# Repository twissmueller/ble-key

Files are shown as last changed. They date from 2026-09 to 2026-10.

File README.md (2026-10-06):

# ble-key

A Bluetooth Low Energy interface for a Morse **key**, built on a Seeed Studio XIAO board —
either the [XIAO ESP32-S3](https://wiki.seeedstudio.com/xiao_esp32s3_getting_started/) or the
[XIAO nRF52840](https://wiki.seeedstudio.com/XIAO_BLE/).

Plug in your own straight key or iambic paddle. The board reads the contacts (dit / dah),
debounces them, and streams **timed keying edges** over BLE as notifications to the
[Longpath](https://wissmueller.net/en/longpath.html) Morse-training app, which produces the
audio/sidetone and does the training. The device itself makes no sound — it's purely the
key interface. The onboard LED gives instant, BLE-independent visual feedback while keying.

The BLE contract below is simple and app-agnostic — anything that speaks GATT can consume it.
Both boards implement it identically; the app cannot tell them apart.

## Repository layout

| Path | What |
|---|---|
| [`esp32s3/`](esp32s3/) | XIAO ESP32-S3: firmware, pins and wiring, the battery mod ([BATTERY.md](esp32s3/BATTERY.md)) |
| [`nrf52840/`](nrf52840/) | XIAO nRF52840: firmware, pins and wiring, battery |
| [`lib/BleKeyCore/`](lib/BleKeyCore/src/BleKeyCore.h) | Shared firmware: the BLE contract, debounce, LiPo curve, power states |
| [`enclosure/`](enclosure/) | Printable cases — the XIAO case fits both boards |
| `flash.sh`, `monitor.sh` | Build, flash and watch either board |

## Which board?

| | XIAO ESP32-S3 | XIAO nRF52840 |
|---|---|---|
| Keying, LED, BLE contract | ✓ | ✓ |
| Wiring of the paddle jack | `D1` tip, `D2` ring, `GND` sleeve | the same |
| Battery level | LiPo **plus two dividers** soldered on | LiPo only — divider is on the board |
| Charging / charged | extra charge-sense wire | read from the charger on the board |
| Idle sleep | deep sleep, ~14 µA | System OFF, a few µA |
| Current while connected | tens of mA | a few mA (typical figures, not measured here) |

For a battery key the nRF52840 is the better choice: no extra parts and much longer runtime.
The ESP32-S3 key stays supported.

## Getting a key

The BLE key is open hardware — get one in whichever way suits you:

1. **Build it yourself** — source the parts ([Hardware](#hardware)) and flash the firmware
   ([Build & flash](#build--flash)); everything you need is in this repository.
2. **Order a parts kit** — I'll send you the board and connectors, you assemble and flash.
3. **Order a ready-built key** — assembled, flashed, and tested.

For a parts kit or a ready-built key, email
[hello@wissmueller.net](mailto:hello@wissmueller.net) with your shipping address. The Longpath
app offers the same three options (with pre-filled order emails) in its BLE-key dialog — keep
that dialog and this section in sync.

## BLE contract

The device advertises as **`Paddle`** with one service and one notify characteristic.
On every debounced paddle edge it sends a **5-byte little-endian** packet:

```
byte 0     : event   (uint8)
bytes 1..4 : millis  (uint32, little-endian) — device millis() at the edge
```

Events:

| Value | Event |
|---|---|
| `0` | `DIT_DOWN` |
| `1` | `DIT_UP` |
| `2` | `DAH_DOWN` |
| `3` | `DAH_UP` |

The client reconstructs element and gap timing from consecutive timestamps. The board
re-advertises automatically after a central disconnects, so a client can reconnect
without power-cycling.

### Battery level

With a battery the key additionally exposes the SIG-standard
**Battery Service `0x180F`** with the **Battery Level characteristic `0x2A19`** (`uint8`,
0–100 %, read + notify). The level is re-measured every 10 s while the key is idle and
notified only when it changes; a client reads it once after connecting and then subscribes.
The service is *not* advertised — clients find it during service discovery — and it sits
next to the Longpath service without touching the packet format or UUIDs above. Clients
that do not know it, and older app builds, simply ignore it. Whether a key without a cell
exposes the service at all depends on the board (see its README); either way the Longpath
app then shows no level.

The percentage comes from an open-circuit LiPo discharge curve (3.30 V → 0 %, 4.20 V →
100 %, flat in the middle), not a linear map. On USB power the
measurement would only see the charger, so the key publishes **`0xFF` = level unknown** instead
of a percentage — outside the SIG's 0–100 on purpose; Longpath shows no level for it, other
clients should treat it the same way — and the idle sleep is off. Below 3.5 V the onboard
LED double-blinks once at boot, independently of BLE.

### Battery power state

Next to the level the same service carries the SIG-standard **Battery Power State
characteristic `0x2A1A`** (`uint8`, read + notify): bits 0–1 *present*, bits 2–3
*discharging*, bits 4–5 *charging* (each 2 = no, 3 = yes; 0 = unknown), bits 6–7 unused.
The key publishes five values:

| Meaning | Value  | present | discharging | charging |
|---|---|---|---|---|
| unknown | `0x00` | ? | ? | ? |
| on cell | `0x2F` | yes | yes | no |
| charging  | `0x3B` | yes | no | yes |
| charged | `0x2B` | yes | no | no |
| no cell | `0x02` | no | — | — |

Off USB a plausible cell reading means *on cell*. On USB the charger's status line is the
only evidence; how each board reads it is in its README. Anything the key cannot vouch for
stays *unknown*. While *charging* or *charged* the level in `0x2A19`
is the live reading of the cell under charge instead of `0xFF` — a few points high and
climbing; the Longpath app shows it next to "charging" and forces 100 % once the key reports
*charged*. In every other state on USB the level stays `0xFF`. Notified only on change; a
client reads it once after connecting and subscribes.

### Idle sleep

A battery key enters deep sleep after ten minutes without a paddle edge.
It disconnects the central first, so a client sees a clean disconnect rather than a
supervision timeout, and wakes on either paddle line going LOW. Waking is a reset: the key
advertises again after about half a second, and `millis()` restarts at 0 — clients must
treat a reconnect as a timing resync (Longpath does). A key on USB never sleeps.

### UUIDs

The service and characteristic UUIDs in [`BleKeyCore.h`](lib/BleKeyCore/src/BleKeyCore.h) are the **fixed Longpath contract**
— the app looks for exactly this service, so leave them unchanged if your key should work
with Longpath (whether self-built, from a kit, or bought ready-made). Only when building
for a *different* client should you mint your own pair (`uuidgen`, run twice) and replace
`SVC_UUID` / `CHR_UUID` there — both boards pick them up.

## Build & flash

Requires [`arduino-cli`](https://arduino.github.io/arduino-cli/) and the core for your board:

```sh
# XIAO ESP32-S3
arduino-cli core install esp32:esp32
arduino-cli lib install "NimBLE-Arduino"

# XIAO nRF52840 (Seeed's non-mbed core, which brings the Bluefruit BLE library)
arduino-cli config add board_manager.additional_urls \
  https://files.seeedstudio.com/arduino/package_seeeduino_boards_index.json
arduino-cli core update-index
arduino-cli core install Seeeduino:nrf52
```

Then:

```sh
./flash.sh esp32s3            # or: ./flash.sh nrf52840
./flash.sh nrf52840 /dev/cu.usbmodemXXXX   # pass the port explicitly

./monitor.sh                  # serial monitor at 115200 baud, either board
```

`flash.sh` passes the shared `lib/BleKeyCore` to arduino-cli with `--library`; a manual
`arduino-cli compile` needs the same flag. Bench builds and board-specific notes are in
[esp32s3/README.md](esp32s3/README.md) and [nrf52840/README.md](nrf52840/README.md).

## License

[MIT](LICENSE) © 2026 Tobias Wissmüller

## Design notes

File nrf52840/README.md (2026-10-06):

# ble-key on the XIAO nRF52840

Firmware for the [Seeed Studio XIAO nRF52840](https://wiki.seeedstudio.com/XIAO_BLE/). The BLE
contract, the build tools and the case are shared with the ESP32-S3 key and described in the
[main README](../README.md). The board-independent firmware lives in
[`../lib/BleKeyCore`](../lib/BleKeyCore/src/BleKeyCore.h); this sketch adds the Bluefruit BLE
stack, the pins, the battery readings and System OFF.

## Pins and wiring

| Signal | XIAO pin | nRF pin | Notes |
|---|---|---|---|
| Dit | `D2` | P0.28 | `INPUT_PULLUP`, pressed = LOW |
| Dah | `D1` | P0.03 | `INPUT_PULLUP`, pressed = LOW |
| Keying LED  | blue LED | P0.06 | active-low |
| Low battery | red LED  | P0.26 | active-low, double blink at boot below 3.5 V |
| Battery | on board | P0.31 | 1 MΩ / 510 kΩ divider, enabled by P0.14 LOW |
| Charging | on board | P0.17 | BQ25100 `~CHG`, LOW while charging |
| USB power | on chip  | — | the nRF52840's VBUS detector |

The paddle jack is wired exactly as on the ESP32-S3 (`D1` tip, `D2` ring, `GND` sleeve). With
that wiring, dit and dah came out swapped on the nRF prototype, so the firmware reads dit on
`D2` and dah on `D1` — the ESP32-S3 sketch does it the other way round. For
the battery only the cell is soldered on — none of the resistors or wires of the ESP32-S3's
battery strips are needed here:

Wiring: XIAO nRF52840 to a 3.5 mm TRS jack — D1 to tip (dit), D2 to ring (dah), GND to sleeve; optional LiPo on the BAT pads, with the battery divider on P0.31, the BQ25100's ~CHG on P0.17 and the VBUS detector already on the board

## Battery

Solder a single-cell LiPo with protection circuit to the `BAT` pads on the underside — that is
the whole mod. The XIAO nRF52840 has the charger, the voltage divider and the charge-status
line on board, and the chip sees USB power itself. Cell choice, polarity and soldering are the
same as for the ESP32-S3 key: see [`../esp32s3/BATTERY.md`](../esp32s3/BATTERY.md) up to and
excluding "The voltage divider".

- **Battery Service:** always present. Off USB the key can only be running from a cell; on USB
  without one it reports the level as `0xFF` (unknown), like the ESP32-S3 key.
- **Power state:** off USB a plausible reading means *on cell*. On USB, `~CHG` held low for two
  3 s windows means *charging*; released after that, *charged*. Released from the start (a full
  cell or no cell) stays *unknown*. *No cell* is never reported — what the BQ25100 does on
  `~CHG` without a cell is not verified yet.
- **Charge current:** the core's default, 50 mA. Seeed's wiki describes how P0.13 switches it to
  100 mA; the firmware leaves it alone.
- **VBAT_ENABLE (P0.14)** is driven LOW for good: with it HIGH, as the core leaves it, a full
  cell lifts P0.31 above the chip's supply through the divider. LOW costs about 3 µA.

## Idle sleep

Off USB the key enters **System OFF** after ten idle minutes, with both paddle lines armed
(pull-up, sense LOW). The next dit or dah wakes it; that press is consumed by the boot, as on
the ESP32-S3. Plugging in USB wakes a sleeping key too. The GPIO latch tells the firmware which
paddle woke it (`[paddle] woke on key press (dah)`).

## Build & flash

```sh
./flash.sh nrf52840           # from the repository root
```

FQBN `Seeeduino:nrf52:xiaonRF52840` — Seeed's **non-mbed** core, which brings Adafruit's
Bluefruit library. `flash.sh` uploads over the USB serial bootloader. Two quirks of that core
it works around: it calls `python` (macOS only has `python3`), and its `adafruit-nrfutil` stops
under an ASCII locale.

If the board does not show up as a serial port (crashed firmware), double-tap the reset button:
the bootloader comes up with its own port and a USB drive, and `flash.sh` works
again.

### Bench build

Shorter idle sleep, from the repository root:

```sh
arduino-cli compile --fqbn Seeeduino:nrf52:xiaonRF52840 --library lib/BleKeyCore \
  --build-property "compiler.cpp.extra_flags=-DIDLE_SLEEP_MS=20000" nrf52840
```

System OFF has no timer, so there is no `SLEEP_TEST_TIMER_S` here; wake the key with the paddle.
The serial monitor misses the boot log after a wake; the firmware repeats the essentials 3 s
after boot (`[paddle] ready — woke on dit, advertising`).

## Measured

- **No cell, on USB (6 October 2026):** the battery pin reads 3748 mV — the charger's output,
  not a cell. The key correctly publishes the level as `0xFF` and the power state as unknown.
  This is why a reading on USB is never trusted without `~CHG` having shown a charge.

## Not yet measured

- Sleep current in System OFF and current while connected.
- Battery readings against a meter (divider tolerance, ADC offset).
- `~CHG` at the end of a charge (with no cell it did not report charging).
- Which of the case's light holes the RGB LED lines up with.

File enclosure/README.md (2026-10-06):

# Printable cases

`enclosure.py` (build123d, Python CAD) builds the case for a XIAO ESP32-S3 or XIAO nRF52840 with a
3.5 mm paddle jack, in two versions. It writes STEP and STL per part to `out/`, plus a lid STL turned
over for printing. `preview.html` shows both cases in 3D after the script has run.

| Case | Outer size, Cliff FC681374V (default) | with `--jack pj392` |
|---|---|---|
| USB only | 48.5 × 25.0 × 14.1 mm | 43.0 × 25.0 × 13.6 mm |
| Battery under the board | 53.2 × 25.3 × 20.2 mm | 53.2 × 25.3 × 19.2 mm |

**The jack.** The default is the **Cliff FC681374V** (Reichelt 228160): M8 × 0.75 thread through an
8.5 mm hole in the full 2 mm wall, ring nut outside, square body 10.5 × 9 × 13.5 mm plus 4 mm pins
inside. A block under the lid sits on the body's flat top, so tightening the nut cannot turn it.
Pins: 3 = tip (D1), 2 = ring (D2), 1 = sleeve (GND), 4 = switch contact, unused. The **PJ-392**
(TinyTronics; round 8 mm body, 6.5 mm hole, 12 mm deep) still works with `--jack pj392`, which
writes the same file names, so regenerate before printing.

```bash
uv venv --python 3.12 .venv && uv pip install --python .venv/bin/python -r requirements.txt
.venv/bin/python enclosure.py          # MJF / SLA print service, 0.25 mm fit
.venv/bin/python enclosure.py --fdm    # own FDM printer (PETG), 0.35 mm fit → out/usb-fdm/, out/battery-fdm/
.venv/bin/python enclosure.py --snap-test   # FDM test pieces for the snap lips → out/snap-test-fdm/
.venv/bin/python enclosure.py --jack pj392   # any of the above for the PJ-392 instead of the Cliff jack
```

**Printing the XIAO case in PETG on an FDM printer** (e.g. Bambu Lab A1 mini): use
`out/usb-fdm/ble-key-usb-fdm-base.stl` upright, floor on the plate, and
`out/usb-fdm/ble-key-usb-fdm-lid-print.stl` (already turned over). 0.2 mm layers, 3 walls, 20 %
infill, no supports. Screws: 2 × countersunk self-tapping 2.2 × 6.5 (DIN 7982); the lid has 90°
countersinks for them.

**Holding the board:** in both XIAO cases the board clicks in: four springy snap lips beside its
corners hook 0.25 mm over the long edges, so it stays put with the lid off. With the lid on, the
tab presses on the USB-C socket and two stiff L-shaped ribs press on the far corners. If a lip
holds too little or breaks, tune `SNAP_HOOK`, `SNAP_T` and `SNAP_ROOT` in `enclosure.py`. Try the
fit first with the test pieces from `--snap-test`: a 5.8 mm slice of each base around the far
supports, and a 15 mm stand-in for the board's end (or use the real XIAO).

## The XIAO battery case

Three layers instead of a second compartment: the LP-552035 lies flat on the floor, a 3 mm wiring
layer sits above it, and the XIAO rests on four 45° brackets on the side walls on top (no
supports needed when printing). Each bracket has a springy snap lip with a 0.25 mm hook over the
board's edge, so the board clicks in and stays put with the lid off; with the lid on, two stiff
ribs hung from its lip press the far corners down right above the brackets. The BAT pads and the
paddle wires are soldered on the board's underside, so every wire runs in that layer, out of sight. The jack sits above the cell; under it
is a 10 mm bay for the mated JST-PH pair and the spare lead, separated from the cell by a low rib
with a gap for the lead. Four countersunk screws go into bosses that hang from the side walls
above the cell. Keep the joints under the board flat — 3 mm is the limit — and tape the cell to
the floor, it has 0.5 mm of play upwards.

## XIAO ESP32-S3 and XIAO nRF52840

Both XIAO cases fit either board: the two share the outline, board thickness and USB-C position
(checked against Seeed's STEP models, `vendor/XIAO-ESP32S3 v2.step` and
`vendor/nrf/XIAO-nRF52840 v15.step`), and the lid's two hold-down ribs sit on bare board on both.
The light holes are placed for the ESP32-S3's LEDs; on the nRF52840 they are not verified.

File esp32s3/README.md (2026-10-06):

# ble-key on the XIAO ESP32-S3

Firmware and wiring for the [Seeed Studio XIAO ESP32-S3](https://wiki.seeedstudio.com/xiao_esp32s3_getting_started/).
The BLE contract, the build tools and the case are shared with the nRF52840 key and described in
the [main README](../README.md). The board-independent firmware lives in
[`../lib/BleKeyCore`](../lib/BleKeyCore/src/BleKeyCore.h); this sketch adds NimBLE, the pins,
the ADC and the deep sleep.

## Pins and wiring

| Signal | XIAO pin | GPIO | Notes |
|---|---|---|---|
| Dit | `D1` | GPIO2  | Tip, `INPUT_PULLUP`, pressed = LOW |
| Dah | `D2` | GPIO3  | Ring, `INPUT_PULLUP`, pressed = LOW |
| LED | `GPIO21` | — | `LED_BUILTIN`, active-low |
| Battery | `A0` | GPIO1  | Divider tap, ADC — battery mod only |
| USB power | `D10` | GPIO9  | Divider tap from `5V` (VBUS), ADC — battery mod only |
| Charge LED  | `D3` | GPIO4  | Tap on the charge-LED net, `INPUT_PULLUP`, LOW = LED on — charge-sense wire only |

Wire each key/paddle contact between its input pin and ground; the internal pull-ups mean
no external resistors are needed. A straight key uses the dit line only; an iambic paddle
uses both. The tip/ring assignment matches a standard 3.5 mm TRS paddle plug:

Wiring: XIAO ESP32-S3 to a 3.5 mm TRS jack — D1 to tip (dit), D2 to ring (dah), GND to sleeve; optional LiPo on the BAT pads with a 2 × 220 kΩ divider into A0, a second 2 × 220 kΩ divider from 5V into D10 to sense USB power, and the optional charge-sense wire from the charge LED's cathode pad throu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

## Battery (optional)

The key runs from USB-C as it is. For a cordless key, solder a single-cell LiPo to the
`BAT` pads on the underside of the XIAO — it has the charger on board — and add a
**2 × 220 kΩ voltage divider** from `BAT+` to `GND`, tapped into `A0`, so the firmware can
measure the cell and report its level to the app. Add a **second 2 × 220 kΩ divider from the
`5V` pin to `GND`, tapped into `D10`**: the 5V pin is USB VBUS, so this tells the firmware
when the key is on USB power — from a host, a charger or a power bank alike. That matters
because on USB the `BAT+` pad carries the charger's output, not the cell, and would read as a
meaningless "62 %" even with no cell fitted. Cell choice, polarity, soldering order and
runtime expectations are in [BATTERY.md](BATTERY.md).

To see *charging* in the app as well, add the **charge-sense wire**: one wire (through a
100 kΩ series resistor) from the net of the red charge LED into `D3`. The charge IC drives
that LED and nothing else — flashing while a cell charges, off when it is full, solid for
~30 s after plug-in without a cell — and reading it is the only way the firmware can tell
those apart. With the wire the key reports charging / charged / no cell over BLE and keeps
publishing the live level while charging; without it, USB shows the plain connected chip
as before. Details in [BATTERY.md](BATTERY.md#the-charge-sense-wire); the last strip of the wiring diagram shows it.

One build fits every key: at boot the firmware checks whether the mod is actually fitted
(VBUS on `D10`, or a plausible cell voltage on `A0`, steady over a few samples) and switches
the battery features on or off accordingly. A battery key reports its level over BLE and
**deep-sleeps after ten idle minutes** — the next dit or dah wakes it (that press is consumed
by the boot; keying resumes with the following one, and the Longpath app reconnects on its
own). A stock USB key exposes no Battery Service and never sleeps. To leave the battery code
out of the image altogether, build with `-DBATTERY_MOD=0` (see [Bench builds](#bench-builds)).

## How the power state is read

Off USB a plausible cell reading means *on cell*. On USB the charge LED, read through the
charge-sense wire on `D3`, is the only evidence: flashing → *charging*; dark for two windows
after having flashed → *charged*; solid for two windows without ever flashing → *no cell*.
Dark from the start says nothing (a key booted on USB, a cell that was already full, or a key
without the wire) and stays *unknown*. USB power itself is sensed on `D10`.

## Idle sleep

The battery key deep-sleeps after ten idle minutes and wakes on either paddle line through
ext1. Details, including the RTC pull-up handling that makes this work, are in
[BATTERY.md](BATTERY.md#idle-sleep).

## Build & flash

```sh
../flash.sh esp32s3           # from the repository root: ./flash.sh esp32s3
```

FQBN `esp32:esp32:XIAO_ESP32S3`, BLE through [NimBLE-Arduino](https://github.com/h2zero/NimBLE-Arduino).

### Bench builds

Two compile-time overrides make the idle sleep testable without waiting ten minutes
(run from the repository root):

```sh
# sleep after 20 s instead of 10 min
arduino-cli compile --fqbn esp32:esp32:XIAO_ESP32S3 --library lib/BleKeyCore \
  --build-property "compiler.cpp.extra_flags=-DIDLE_SLEEP_MS=20000" esp32s3
# additionally wake by timer after 15 s, to test the wake/boot path without a key
arduino-cli compile --fqbn esp32:esp32:XIAO_ESP32S3 --library lib/BleKeyCore \
  --build-property "compiler.cpp.extra_flags=-DIDLE_SLEEP_MS=20000 -DSLEEP_TEST_TIMER_S=15" esp32s3

# leave the battery code out of the image entirely (no ADC, no Battery Service, no sleep)
arduino-cli compile --fqbn esp32:esp32:XIAO_ESP32S3 --library lib/BleKeyCore \
  --build-property "compiler.cpp.extra_flags=-DBATTERY_MOD=0" esp32s3
```

A sleeping key has no USB port (native USB dies with the chip), so a build that cannot wake
can only be re-flashed after a power cycle. Hold the key down while plugging USB back in —
a held paddle keeps the firmware awake indefinitely — and flash then. The serial monitor
misses everything printed before it attaches, which after a wake is the whole boot log;
the firmware therefore repeats the essentials once, 3 s after boot
(`[paddle] ready — woke on dit, advertising`).

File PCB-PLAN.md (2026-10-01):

# Custom PCB plan — nRF52840 key, built by AISLER

**Status:** schematic, layout and case done (`hardware/`, `enclosure/`); design uploaded to AISLER
and quoted on 1 October 2026; nothing ordered. Prices are **net (no VAT)** unless marked. Figures
marked *estimate* do not come from a price list or quote.

## Why

The XIAO ESP32-S3 does far more than the key needs (two cores, Wi-Fi, camera support) and costs
battery life. The key needs BLE, two inputs, a battery measurement, a charger and USB-C. A custom
board with an **nRF52840** module gives:

- much lower power draw while connected, so the battery version lasts far longer between charges;
- no hand wiring: USB-C, the 3.5 mm jack and the battery connector sit on the board, and the
  housing has openings exactly where they are;
- real charge and USB-power signals from the charger chip instead of the two voltage dividers and
  the soldered charge-sense wire;
- the same product every time, assembled by AISLER in Germany.

It is **not cheaper per unit** than the XIAO build at 30 pieces. The gain is battery life, build
quality and no assembly work.

## The board

**48 × 27 mm, 2 layers, 1.6 mm, ENIG**, all parts on the top side, all SMD (see `hardware/`).

| Function | Part | Price @30 | Source |
|---|---|---|---|
| BLE + MCU | Raytac **MDBT50Q-1MV2** (nRF52840, chip antenna, FCC/CE/TELEC certified), sold as Seeed 113990582 | 10.27 € | [DigiKey](https://www.digikey.de/de/products/detail/seeed-technology-co-ltd/113990582/9697025) |
| Charger with power path | TI **BQ24074RGTR** — runs the key from USB while it charges; CHG and PGOOD pins go straight to GPIOs | 1.41 € | [DigiKey](https://www.digikey.de/de/products/detail/texas-instruments/BQ24074RGTR/2047269) |
| USB-C | GCT **USB4105-GF-A** (USB 2.0, 16 pin) | 0.54 € | [DigiKey](https://www.digikey.de/de/products/detail/gct/USB4105-GF-A/11198441) |
| Paddle jack | Same Sky **SJ-3523-SMT-TR** (3.5 mm TRS, right angle) | 0.60 € | [DigiKey](https://www.digikey.de/de/products/detail/same-sky-formerly-cui-devices/SJ-3523-SMT-TR/281297) |
| Battery connector | JST **S2B-PH-SM4-TB** (PH 2.0, SMD) | 0.36 € | [DigiKey](https://www.digikey.de/de/products/detail/jst-sales-america-inc/S2B-PH-SM4-TB/926655) |
| USB ESD protection | ST **USBLC6-2SC6** | 0.28 € | [DigiKey](https://www.digikey.de/de/products/detail/stmicroelectronics/USBLC6-2SC6/1040559) |
| Reset / bootloader button | Panasonic **EVP-AKE31A** (side push) | 0.41 € | [DigiKey](https://www.digikey.de/de/products/detail/panasonic-industry/EVP-AKE31A/8568272) |
| 2 status LEDs | Würth 150060VS75000 (0603) | 0.26 € | [DigiKey](https://www.digikey.de/de/products/detail/w%C3%BCrth-elektronik/150060VS75000/4489906) |
| Resistors, capacitors, battery divider | 0603 passives, ~15 pieces | ~1.50 € *estimate* | — |
| **Parts per board** | | **≈ 15.60 €** | |

Design notes:

- **Why this module:** it is the module on Adafruit's Feather nRF52840, so its UF2 bootloader runs
  unchanged and updates work by dragging a file onto a USB drive. Its VDDH input takes the battery
  voltage directly, so no voltage regulator is needed. The certification covers the radio, as long
  as the antenna area stays clear of copper — the module goes at a board edge.
- **The module has pads underneath (LGA).** That is fine for AISLER's machines but rules out hand
  soldering. Their guide for modules: [setting up SoMs for assembly](https://community.aisler.net/t/setting-up-socs-for-assembly/3443).
  Suitability of this exact module should be confirmed with them before the first order.
- **Battery version and USB-only version are the same board**; the USB-only key simply has no
  cell plugged in.
- **Pins follow the Feather nRF52840 where possible** (LEDs, button), so the Feather board
  definition in the Arduino core can be used without a custom one.
- **Programming pads (SWD)** for the one-time bootloader flash: SWDIO, SWCLK, GND, VDD, RESET,
  as a Tag-Connect footprint so a cable clips on without a connector on the board.
- **Charge current** set to ~175 mA (0.5 C for 350 mAh), so a full charge takes about 2½ hours
  instead of the XIAO's 7.

## Firmware

Port `ble-key.ino` to the **Adafruit nRF52 Arduino core** (Bluefruit library):

- the Longpath contract stays: same service and characteristic UUIDs, same event format, same
  Battery Service;
- battery level from the divider, USB power from PGOOD, charging from CHG — the three readings
  the current firmware has to infer from analog voltages become plain pin reads;
- deep sleep becomes nRF52 **System OFF** with wake-up on the dit or dah pin (a few µA);
- `flash.sh` switches to the Feather nRF52840 board and uploads over USB.

The port can start **now, before any board exists**, on a Seeed XIAO nRF52840 — same nRF52840
chip, same USB bootloader, and it fits the housing in `enclosure/` unchanged.

## Housing

`enclosure/board_case.py` builds the case around the board, USB-only (52.4 × 31.6 × 12.4 mm) or with
the cell in the lid above the board (52.4 × 31.6 × 18.8 mm). Printed by an outside service in MJF
PA12 (dyed black) — AISLER makes no enclosures. See `enclosure/README.md`.

## Costs

### AISLER quote, 1 October 2026

From the uploaded design (project TBHYNBKB, revision 1), with every part assigned and prices
calculated. Net prices, **plus 19 % VAT**, valid 24 hours; dispatch about 18 working days after
ordering. Service "Amazing Assembly": 2 layers, 1.6 mm, ENIG, green, one-sided assembly, 36 parts
(24 different).

| Assembled boards | Net total | Per board |
|---|---|---|
| 1 | 327.18 € | 327.18 € |
| 3 | 406.56 € | 135.52 € |
| 10 | 712.19 € | 71.22 € |
| **30** | **1,423.21 €** | **47.44 €** |

### Where the money goes

The quote splits into three parts. Bare boards and parts come straight from AISLER's own price
lists; assembly is what is left of the total.

| Per board | 1 board | 10 boards | 30 boards |
|---|---|---|---|
| Bare PCB (ENIG) | 16.42 € *(set of 3)* | ~2.70 € *(set of 12)* | 1.68 € |
| Parts, as AISLER buys them | 132.28 € | 33.23 € | ~31.40 € *(between their 10 and 50 prices)* |
| Assembly | ~178 € | ~35.50 € | ~14.40 € |
| **Total** | **327.18 €** | **71.22 €** | **47.44 €** |

The cost drivers, in order:

1. **Parts at about twice their list price.** The parts add up to about 16 € per board at
   distributor list prices, but AISLER charges 33.23 € at 10 boards and 29.57 € at 50. Their parts
   price includes "assembly surplus and sourcing and handling costs" and minimum order quantities.
   Even at 1,000 boards it is still 23.81 €.
2. **The radio module.** It is the only part AISLER marks as a large price impact: 8.85 € each as
   Seeed 113990582. The listing also says "the factory is currently not accepting orders", so stock
   is finite.
3. **Assembly setup.** Roughly 180 € for a single board and about 430 € for 30, so it is mostly a
   fixed cost per order. AISLER does not publish the rates, but the cost is known to grow with the
   number of *different* parts (24 today), more than with the number of boards.
4. **The bare board is negligible:** 1.68 € per board at 30.

Compared with the earlier estimate (27–30 € per key including the case), assembled boards alone
cost about 47 € at 30. The parts surplus and the assembly setup were both underestimated.

### Ways to bring it down

| Change | Effect |
|---|---|
| **Order more at once** | Parts drop from 33.23 € (10) to 29.57 € (50) and 26.55 € (100) per board, and the assembly setup spreads further. |
| **Fewer different parts** (24 → about 17) | Cuts the per-part setup work: <br>– drop the reset button (the bootloader is reachable over USB, recovery over SWD), which also removes the tongue from the case; <br>– use the module's internal pull-ups for PGOOD and CHG (R6, R7); <br>– one 10 µF value for all bulk capacitors (C1–C3 at the charger too, within the BQ24074's ranges); <br>– 1 kΩ instead of 470 Ω for the paddle series resistors; <br>– 5.1 kΩ for ILIM as well (about 300 mA input limit, enough for 175 mA charging); <br>– two LEDs of the same colour. |
| **Supply the module yourself** | Raytac's own listing is about 6 € including shipping, against 8.85 € plus AISLER's surplus. Costs a one-off 15 € fee per supplied part number, so it pays off from about 10 boards. It also protects the run against the Seeed listing running dry. |
| **Ask for a personal quote** | AISLER's account management quotes larger or repeat runs individually. |

Each change in the "fewer different parts" row needs a schematic change and a new upload to see
its real effect; AISLER prices only the design it has.

### JLCPCB quote, 1 October 2026

Same design, uploaded to JLCPCB (`hardware/jlcpcb/`), 30 boards, ENIG, economic assembly on the
top side. Prices in USD, before shipping (DHL about 23 $) and EU import VAT:

| Item | 30 boards |
|---|---|
| Bare boards | 76.15 $ — of which about 51 $ come from the 0.25 mm vias, which make JLCPCB add via plugging and a 4-wire test; with 0.3 mm vias the boards cost 26 $ |
| Parts (22 of 24 types) | 140.35 $ |
| Extended-part fees | 30.90 $ |
| Setup, stencil, assembly, nitrogen reflow | 17.44 $ |
| **Total without module and switch** | **264.84 $ (8.83 $ per board)** |

Not in that total, because JLCPCB has no stock: the **module** (MDBT50Q-1MV2, listed at 18.94 $
each, so about 570 $ for 30 if pre-ordered there) and the **reset switch**. With the module bought
through JLCPCB the order comes to roughly **850–870 $**, about 29 $ per board; with modules bought
elsewhere at 9–10 € each and sent in, considerably less. Either way about half of AISLER's
1,423 € net.

To order there: pre-order or consign the module and switch, tick "Confirm Parts Placement" (JLCPCB's
model of the jack sits about 0.7 mm off the pads; their engineers correct it), and keep in mind
that shipping from China and customs add a few days and the import VAT.

### Seeed Fusion quote, 1 October 2026

Same design (`hardware/seeed/`), 30 boards, ENIG, 0.25 mm drill, 4/4 mil, 0.1 mm mask dam. USD,
free DHL express shipping to Germany, before EU import VAT and coupons:

| Item | 30 boards |
|---|---|
| Bare boards | 162.70 $ (the tight drill/trace/mask rules double the board price) |
| Parts, 17 of 24 lines matched | 207.41 $ |
| Assembly | 332.70 $ |
| Setup and consumables | 65.00 $ |
| **Subtotal** | **767.81 $** |

Not yet priced: the module (Seeed SKU 113990582) and six resistor values, which Seeed checks by
hand within a working day once the order is in the cart. With the module at about 9–10 $ the total
comes to roughly **1,050–1,100 $, about 35–37 $ per board.** Per-board prices fall to 18.77 $ (50)
and 13.28 $ (100) for the matched part of the quote.

### Comparison, 30 assembled boards

| Supplier | Total | Per board | Status |
|---|---|---|---|
| AISLER (Germany) | 1,423.21 € net | 47.44 € | complete quote, all parts in stock |
| Seeed Fusion (China) | ~1,050–1,100 $ | ~35–37 $ | module and 6 resistors priced on manual review |
| JLCPCB (China) | ~850–870 $ | ~29 $ | module and reset switch out of stock there |

### Everything else (unchanged estimates)

| Item | Cost |
|---|---|
| Cells, LP-552035 | 4.18 € each ([Eckstein](https://eckstein-shop.de/LiPo-Battery-Lithium-Ion-Polymer-Battery-37V-350mAh-with-JST-PHR-2-Connector-LP552035-EN)) |
| Cases, MJF PA12, from an EU print service | ~3–6 € per case *estimate* |
| Screws, 2 × M2 × 8 per case | ~0.20 € |
| Once: Raspberry Pi Debug Probe, Tag-Connect TC2030 cable, XIAO nRF52840 for the firmware port | ~65 € *estimate* |

**Per key at 30, with battery: about 47.44 + 4.18 + ~4.50 + 0.20 ≈ 56 € net.**

### Not included: selling the keys

Selling assembled keys in the EU makes you the manufacturer, which brings costs that are not in
the tables above and need checking before the first sale:

- **CE marking under the Radio Equipment Directive.** The certified module helps a lot, but the
  finished product still needs a declaration of conformity; a pre-scan at a test lab is the usual
  safeguard. This can cost more than the whole production run.
- **WEEE registration** (stiftung ear) for electronic devices sold in Germany.
- **Battery registration** (BattG / EU battery regulation) if keys ship with a cell — or sell the
  cell separately, or let buyers fit their own.

Kits the buyer assembles and the open-hardware files themselves are a different situation.

## Order of work

1. **Firmware port** on a XIAO nRF52840 — proves BLE, sleep and battery life before any money
   goes into boards.
2. ~~Schematic and layout in KiCad~~ — done, with MPN fields filled in.
3. ~~Upload to AISLER~~ — done, quote above. Still to do: confirm the module's bottom pads with
   their support, and decide on the cost reductions.
4. **Prototype run of 3**, housing variant printed alongside. Test charging, range, sleep current.
5. Fixes, then **production run of 30**.

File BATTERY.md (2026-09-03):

# Battery mod — running the key on a LiPo

**Status:** hardware path is verified against the Seeed wiki and low-risk. The firmware
measures the cell through a 2 × 220 kΩ divider, reports the level to the app over the
standard BLE Battery Service (see [Battery level](#battery-level-over-ble)) and deep-sleeps
after ten idle minutes, waking on the next key press (see [Idle sleep](#idle-sleep)). What
is left is measuring on real hardware (see [TODO](#todo--firmware-work)). The stock,
USB-powered key is unaffected — this is an optional mod for people who want a cordless key.

The [XIAO ESP32-S3](https://wiki.seeedstudio.com/xiao_esp32s3_getting_started/) has a LiPo
charger on board, so going cordless needs no extra charging module: solder a cell to two
pads and the same USB-C port that flashes the board also charges it.

## What the board gives you

- Two solder pads on the **underside**, labelled `BAT`, for a single-cell 3.7 V LiPo.
- An **on-board charge IC**. Plug in USB-C and the cell charges while the board keeps
  running and keying — no need to disconnect anything.
- A red charge LED: on when USB is connected *without* a battery (it gives up after ~30 s),
  flashing while charging, off when the cell is full.
- **14 µA in deep sleep** (per Seeed's specification table), which is what makes a
  battery-powered key practical at all.

Three constraints that shape every decision below:

- **The charge current is only 50 mA** (3.8 mA trickle) on the plain XIAO ESP32-S3. Note
  that the *Sense* variant charges at 100 mA — do not carry that number over. 50 mA is
  fixed in hardware and cannot be raised in firmware, so **capacity costs you charge
  time**: a 500 mAh cell needs roughly 10 hours from empty. That is fine overnight and
  painful otherwise.
- The charger has **no NTC / temperature input**. The cell's own protection circuit is the
  only safety net, which is why the cell choice below is not optional.
- Seeed states plainly that there is **no GPIO for battery voltage**: *"we cannot get the
  battery voltage at the software level by reading the analog value of one of the GPIOs."*
  The state-of-charge display therefore needs an external divider — two resistors, see
  [The voltage divider](#the-voltage-divider).

## Choosing a cell

A single-cell 3.7 V LiPo pouch with an **integrated protection circuit (PCM)** —
over-charge, over-discharge, over-current and short-circuit protection built into the tab
end. Cells sold with a JST-PH connector normally have one; bare cells often do not.

**400–500 mAh is the sweet spot here**, and the 50 mA charge current is the reason: a
larger pack does not buy runtime you need (the key sleeps at 14 µA between sessions) but
it does stretch charging past a night. Physical size is rarely the constraint — even a
500 mAh pouch at ~35 × 30 × 5 mm disappears into the base of a key, next to a board that
is only 21 × 17.5 mm.

## Shopping list (German shops)

Prices are VAT-inclusive and were checked in August 2026 — verify before ordering.

| # | Item | Where | Price |
|---|---|---|---|
| 1 | **LiPo 3.7 V / 500 mAh, JST-PH 2.0, protected** — PKCell LP-503035, ca. 35.5 × 30.0 × 5.05 mm, ~9 cm lead, integrated protection against over-charge, deep discharge and short circuit | [Eckstein LP503035](https://eckstein-shop.de/LiPo-Battery-Lithium-Ion-Polymer-Battery-37V-500mAh-with-JST-PHR-2-Connector-LP503035-EN) · [BerryBase Art. 70398](https://www.berrybase.de/lp-503035-lithium-polymer-lipo-akku-3-7v-500mah-mit-2-pin-jst-stecker) | 5.19 € (Eckstein) |
| 2 | **JST-PH 2.0 mating pigtail** for the `BAT` pads — see the gender note below | [Eckstein 20-pair kit](https://eckstein-shop.de/2Pin-JST-PH-20-Kable-Kit-20-Paare-EN) · [BerryBase extension cable 50 cm](https://www.berrybase.de/en/extension-cable-2-pin-jst-ph-2.0mm-male-female-awg24-50cm) | 5.95 € / ~1 € |
| 3 | **2 × 220 kΩ resistor** (metal film, 0207) for the battery-level divider | [Reichelt 220 kΩ 0207](https://www.reichelt.de/de/de/shop/produkt/widerstand_metallschicht_220_kohm_0207_0_6_w_0_1_-12876) | ~0.10 € each |

**Equally good: the 350 mAh LP-552035** — [Eckstein, 4.97 €](https://eckstein-shop.de/LiPo-Battery-Lithium-Ion-Polymer-Battery-37V-350mAh-with-JST-PHR-2-Connector-LP552035-EN)
or [BerryBase](https://www.berrybase.de/en/lp-552035-lithium-polymer-lipo-akku-3-7v-350mah-mit-2-pin-jst-stecker).
Same connector and chemistry, and at ca. 35 × 20 × 5.5 mm it is a **third narrower** than
the 500 mAh cell, which sits better beside a 17.5 mm wide board. It charges in ~7 h
instead of ~10 h and gives roughly 6–8 h of active keying instead of 8–12 h. Pick by
whether charge time or session length annoys you more; standby life is identical, because
that is set by deep sleep, not capacity. [EXP-Tech](https://exp-tech.de/en/collections/lipo-batteries)
carries the DTP range with the same JST-PH connector. The board itself, if you need
another: [Eckstein, 10.95 €](https://eckstein-shop.de/Seeed-Studio-XIAO-ESP32S3-Dual-Core-24GHz-Wi-Fi-BLE50-Battery-Charge-Supported-EN).

**Check the protection circuit before you buy either.** BerryBase documents integrated
protection for these PKCell packs (over-charge, deep discharge, short circuit); Eckstein's
listings do not state it. On a protected cell you can see the small PCB under the tape at
the tab end. If you cannot confirm it, buy the BerryBase variant.

**Cheapest route: the 0.99 € add-on.** Eckstein's battery pages offer a *JST PH2.0-2P auf
XH2.5-2P Strom-Adapterkabel, 50 mm* as an accessory. Add one to the battery order, cut the
**XH2.5 end** off, and the remaining PH2.0 plug with two open wires is exactly the pigtail
this mod needs — one order, no extra shipping. Two conditions: take the
**"Vorwärtsanschluss"** variant, and expect only ~4 cm of usable wire after the cut, which
is enough for a cell sitting directly under the board but leaves no slack for routing
through a case.

**Connector gender.** LiPo cells ship with the *female* housing, so the exposed pins can
never short against something. The board side therefore needs the **male** half. Before
cutting anything, plug the pigtail into the battery once to confirm it mates. Alternatives
to the add-on cable: the Eckstein kit contains both genders (20 pairs — a lifetime supply),
and the BerryBase male-to-female extension cable can be cut in half, the male end becoming
the board pigtail.

**Polarity is not implied by wire colour.** The same vendor sells the adapter cable in a
"Vorwärtsanschluss" and a "Rückwärtsanschluss" version — identical-looking cables with
*inverted* polarity, and their own listing says to check before use. Ring every pigtail out
with a meter from connector pin to wire end before soldering, no matter which one you
bought.

## Wiring it up

Solder the pigtail to the pads and mate it with the battery's connector, rather than
soldering the cell on directly — you can then swap or remove the cell without reworking
the board.

### Polarity

Seeed documents the orientation unambiguously: **the negative terminal is the pad closest
to the USB-C port, the positive terminal is the pad further away from it.** The silkscreen
prints the sign to the left of each pad, with `BAT` beneath the pair:

```
  −  ▢     pad nearer the USB-C port  = minus (GND)
  +  ▢     pad further from the port  = plus
     BAT
```

**Confirm with a meter before soldering anyway.** Reversed polarity destroys the board
instantly, and silkscreen markings sometimes sit ambiguously between two pads. The check
takes ten seconds: multimeter on continuity, one probe on the pad nearer the USB-C jack,
the other on a known ground — a `GND` pin on the header, or the metal shell of the USB-C
jack itself. It beeps → that pad is minus, and the other is plus.

### Soldering

- Tin the pads first, then lay the tinned wire on and reflow. Do not try to feed solder
  into the joint while holding the wire in place.
- Keep the cell **unplugged** the whole time. Solder the pigtail to the board, verify
  polarity at the connector with a meter, and only then plug in the cell.
- If you do solder a cell directly: strip and attach **one wire at a time**, so the two
  bare ends can never touch. A shorted LiPo is not a minor mistake.
- Add strain relief (a dab of hot glue, or a cable tie to the case). Without it the pads
  eventually tear off the PCB.

### The voltage divider

The board has no battery-sense pin, so the firmware measures the cell through an external
divider: **two 220 kΩ resistors in series from `BAT+` to `GND`, with the midpoint wired to
`A0`** (GPIO1 — free, the key uses only `D1`/`D2` and the LED).

```
  BAT+ ──┤ 220 kΩ ├──┬──┤ 220 kΩ ├── GND
                     │
                    A0
```

- The divider halves the cell voltage: a full cell at 4.2 V shows up as 2.1 V at `A0`,
  comfortably inside the ADC's range at 11 dB attenuation (about 0–3.1 V). The firmware
  multiplies the calibrated reading (`analogReadMilliVolts`) by two.
- 440 kΩ across the cell draws **~9.5 µA** continuously — the same order as the whole
  deep-sleep budget of 14 µA, so it roughly halves standby life versus the datasheet
  figure: still months, not weeks. Two resistors keep the mod dead simple; switching the top
  of the divider with a GPIO instead of wiring it to `BAT+` directly is the refinement if
  those microamps ever matter (see the TODO list).
- Land the top resistor on the `BAT+` pad on the underside (the same pad as the pigtail's
  plus wire), the bottom one on any `GND` — the header pin is the easiest. Tap `A0` from the
  junction. Keep the leads short; the node is high-impedance and picks up noise, which is why
  the firmware averages 16 samples per reading.
- **Do not fit the divider without setting `BATTERY_MOD` accordingly.** With `BATTERY_MOD 1`
  and no divider, `A0` floats and the app shows nonsense; with `BATTERY_MOD 0` the resistors
  are harmless but the level is never read. The default in `ble-key.ino` is `1`.

### The charge-sense wire

On USB the divider cannot say whether a cell is fitted, let alone whether it is full: `BAT+`
carries the charger's output either way. The charge IC knows, but it tells only the red
charge LED next to the USB-C jack — Seeed's schematic connects that LED to nothing else.
So the optional third wire of the mod taps that LED's net and brings it to `D3` (GPIO4):

```
  charge-LED net ──┤ 100 kΩ ├── D3      (LOW = LED on)
```

- Tap the net on the **cathode side** of the LED — the pad that goes to the charge IC's
  open-drain status output, not the one tied to the supply. Find it with a meter: on USB
  without a cell the LED is solid for ~30 s, and the cathode pad then reads near 0 V.
- The **100 kΩ in series** is a precaution, not a divider: if the LED's supply turns out to
  be VBUS rather than 3V3, the resistor limits whatever reaches the GPIO to microamps. The
  firmware reads the pin with its internal pull-up, so the resistor does not change the
  logic level.
- Keep the wire short and route it away from the paddle lines; the net is a slow signal
  (the LED blinks around once a second), so noise is not a worry, but a paddle edge picked up
  on the sense line would be.
- **Without the wire nothing changes**: the pull-up keeps `D3` reading "LED off", which the
  firmware treats as *no evidence*, and the key behaves exactly like a mod without it. There
  is no build flag to set.

The last strip of `wiring.svg` shows the wire. What the firmware makes of the LED is in
[Battery level over BLE](#battery-level-over-ble).

## Charging and power behaviour

- USB-C connected: the board runs from USB and charges the cell simultaneously. Flashing
  with a battery attached is fine. With the charge-sense wire the app shows the live level
  and "charging", then "100 % · charged" once the LED has been dark for a few seconds.
- USB-C disconnected: the board runs from the cell through the on-board regulator, down to
  roughly 3.4 V, below which the cell's protection circuit eventually cuts out.
- Charging is slow by design (50 mA). Plan on charging overnight; there is no fast-charge
  option on this board.

## Runtime expectations

Estimates apart from the deep-sleep figure, which is Seeed's specification. Measure before
trusting them:

| State | Draw | 500 mAh cell |
|---|---|---|
| Connected + advertising, CPU at 240 MHz | 40–60 mA* | ~8–12 h |
| Same, CPU at 80 MHz, long connection interval | 20–30 mA* | ~16–24 h |
| Deep sleep, waiting for the operator | 14 µA + ~10 µA divider* | months |
| Charging from empty | 50 mA in | ~10 h |

\* estimated, not measured.

The firmware deep-sleeps after ten idle minutes, so the hours in the table are *keying
hours*, not wall-clock hours: a key that is used an hour a day lasts a week or two on a
charge, and a key left in a drawer keeps its charge for months. Idle sleep is by far the
biggest power lever here — a Morse key is idle almost all of the time, and 14 µA versus
50 mA is a factor of several thousand.

## Battery level over BLE

Implemented in `ble-key.ino` behind `#define BATTERY_MOD 1`:

- The cell is measured through the divider on `A0` every **10 s while the key is idle**
  (never between two paddle edges — the 16-sample ADC burst must not disturb keying), and
  once at boot.
- The voltage is mapped to a percentage through an **open-circuit LiPo discharge curve**
  (3.30 V → 0 %, 3.70 V → 20 %, 3.85 V → 50 %, 4.00 V → 80 %, 4.20 V → 100 %, linearly
  interpolated). A plain linear map would sit at "60 %" for hours and then collapse,
  because the cell spends most of its life between 3.6 V and 3.9 V. Under load the cell
  sags a little, so the reading is slightly pessimistic while keying — fine for a key.
- The level is published through the SIG-standard **Battery Service `0x180F` / Battery
  Level `0x2A19`** (`uint8` percent, read + notify), notified only when the percentage
  changes. The Longpath contract — the `6e3a…` service, the packet format — is untouched;
  older app builds ignore the extra service.
- Readings outside 2.5–4.6 V are treated as implausible (no cell, no divider) and dropped;
  the last published value stands.
- On USB the divider sees the **charger's output, not the cell**: BAT+ sits at ~3.9–4.2 V
  whether a cell is fitted or not (a bare board on USB reads "62 %"). So USB power is sensed
  separately: a second **2 × 220 kΩ divider from the 5V pin (VBUS) into `D10`** (GPIO9,
  ADC1) reads ~2.5 V whenever anything is plugged in — host, charger or power bank — and
  0 V on the cell. Above 4 V on VBUS the firmware publishes **`0xFF` = level unknown**
  instead of a percentage, and the idle sleep is off (nothing to save, and a sleep would
  cost the first press and drop the serial port). Unplugging restarts the idle clock. A USB
  host on the serial port (`Serial.isPlugged()`) counts as USB power too, as the fallback
  for a key without the VBUS divider.
- Below **3.5 V** the onboard LED double-blinks once at boot — the BLE-independent
  low-battery hint in the spirit of the keying LED.

- With the charge-sense wire the same service carries the SIG-standard **Battery Power
  State `0x2A1A`** (`uint8` bit fields, read + notify, notified on change). The charge LED
  on `D3` is sampled on every loop pass and judged once per 3-second window: two or more
  edges = flashing, otherwise the level at the window's end. Off USB a plausible cell reading
  means *on cell*. On USB only positive evidence makes a claim: flashing → *charging*; dark
  for two windows after having flashed → *charged*; solid for two windows without ever
  having flashed → *no cell* (the IC's "no battery" signal, solid for ~30 s after plug-in).
  Dark from the start — a key booted on USB, a cell already full at plug-in, or a key
  without the wire — stays *unknown*. Two windows of the same verdict are required so that a
  blink slower than one window cannot pass for solid or dark.
- While *charging* or *charged*, `0x2A19` carries the **live reading of the cell under
  charge** instead of `0xFF`: a few points optimistic (charge voltage, not open-circuit) and
  climbing, which is what the app wants to show next to "charging". In every other state on
  USB the level stays `0xFF`.

The Longpath app reads level and power state once after connecting and then subscribes:
the connection chip shows "BLE key connected · 78 %", "· 78 % · charging" or "· 100 % ·
charged", and Settings › Device adds a battery line that turns into a charge hint at 15 %
and below while on the cell. A key without the Battery Service — or one on USB whose power
state is unknown, publishing `0xFF` — shows the plain connected chip and no level.

## Idle sleep

Implemented in `ble-key.ino` behind `BATTERY_MOD 1` (a stock USB key never sleeps — there
is nothing to save, and sleeping costs the first press):

- **When.** After `IDLE_SLEEP_MS` (10 minutes) without a paddle edge, counted from boot or
  the last edge, connected or not. Never while a paddle is held: a held line is LOW and
  would wake the board again immediately, and a key resting on its contact should keep the
  LED on as the visible hint that something is wrong.
- **How.** The firmware first disconnects the central deliberately (so the app sees the
  drop at once instead of after the supervision timeout), stops advertising, re-arms the
  paddle pull-ups as **RTC pull-ups** (`rtc_gpio_pullup_en`) — the plain `INPUT_PULLUP` is
  a digital-domain pull-up and dies in deep sleep, which is the classic way this feature
  fails: both lines float low and the board wakes in a loop. `LED_BUILTIN` is parked HIGH
  and held (`gpio_hold_en`) so the active-low LED cannot glow through the sleep. Then
  `esp_sleep_enable_ext1_wakeup_io()` with `ESP_EXT1_WAKEUP_ANY_LOW` on `GPIO2 | GPIO3`
  (both RTC IOs on the S3) and `esp_deep_sleep_start()`.
- **The RTC-peripheral power domain must stay on AUTO.** The IDF docs suggest keeping
  `ESP_PD_DOMAIN_RTC_PERIPH` powered (`esp_sleep_pd_config(…, ESP_PD_OPTION_ON)`) when
  internal pull-ups are used with ext1. On the XIAO ESP32-S3 with IDF 5.5 that silently
  breaks the wake: measured on the bench, ext1 `ANY_LOW` never fires with the domain forced
  on — not with two pins, not with one, not with a held key — while ext1 `ANY_HIGH` and
  ext0 work in the same configuration. With the domain on AUTO the IDF latches the pad
  configuration (pull-up included) through the sleep via the HOLD feature, and ext1
  `ANY_LOW` wakes on either paddle. Bonus: the RTC peripherals are powered down, so sleep
  current is lower than with the documented approach.
- **Wake.** Any dit or dah press. Deep sleep is a reset: `setup()` runs again, hands the
  wake pins back from the RTC domain (`rtc_gpio_deinit`, or `pinMode` is silently
  ineffective), releases the LED hold, skips the 400 ms serial grace period a cold boot
  affords, and is advertising again after roughly half a second. Expect the **waking press
  to be lost** — it is consumed by the boot, and the app has not reconnected yet. The next
  press keys normally. That is why the timeout is ten minutes: it should only ever trigger
  between sessions, never mid-word.
- **`millis()` across a sleep cycle.** Restarts at 0 — deep sleep is a reset. This is
  harmless: the sleep always coincides with a BLE disconnect, and the Longpath keyers
  detect pauses by wall-clock timeout, not by device timestamps, so the only place a
  consecutive-timestamp comparison spans the wake (the character-gap check) has already
  been flushed by the pause. Verified by reading the keyer code, not on hardware.
- **App side.** The Longpath app re-scans automatically whenever an established link ends
  (`PaddleConnection.keepConnected()`), so the wake needs no "Connect" tap: the chip shows
  "Scanning…" while the key sleeps and flips back to connected within a second or two of
  the wake press. A scan that fails outright (Bluetooth off) backs off up to 15 s between
  attempts so it cannot trip Android's scan throttling.
- **Divider during sleep.** The 2 × 220 kΩ divider stays connected and draws ~9.5 µA
  through the sleep, on top of the ESP32-S3's 14 µA — roughly halved standby life versus
  the datasheet figure, still months. Switching the divider with a GPIO is the obvious
  next refinement if that ever matters.

## TODO — firmware work

Still open in `ble-key.ino`:

- [x] **Sleep when idle, wake on the key** — done, see [Idle sleep](#idle-sleep).
- [x] **RTC pull-ups for the sleep path** — done, part of the sleep entry.
- [x] **`millis()` across a sleep cycle** — restarts at 0; harmless, see above. The app
      treats every reconnect as a hard resync anyway.
- [x] **Verify the sleep path on hardware** — done on a XIAO ESP32-S3 with a TRS-wired
      key (no battery, no divider yet): the board stays asleep indefinitely (no wake loop),
      a held paddle keeps it awake, dit and dah each wake it (wake pin confirmed from the
      ext1 status register), and a wake cycle repeats reliably. USB re-enumerates on wake
      within about a second. Found and fixed on the way: the RTC-peripheral domain must
      *not* be forced on (see [Idle sleep](#idle-sleep)).
- [ ] **Measure the sleep current** with the divider and cell fitted, and the
      wake-to-first-notification time with the app; replace the estimates above.
- [x] **Battery level over BLE** via the SIG-standard Battery Service `0x180F` — done, see
      [above](#battery-level-over-ble).
- [x] **Measuring the cell voltage** through the 2 × 220 kΩ divider on `A0` — done. The
      divider's ~9.5 µA standby draw is accepted for now; switching it with a GPIO belongs
      to the sleep work below.
- [x] **Low-battery indication** independent of BLE — the boot double-blink below 3.5 V.
      Once the key sleeps, this should also run on every wake.
- [ ] **Calibrate the curve against a real cell.** The discharge table is a textbook LiPo
      curve; measure the PKCell packs from the shopping list with a meter at a few points
      and adjust the table if the percentages feel off.
- [ ] **Lower the connected-state draw**: CPU at 80 MHz, and a longer BLE connection
      interval. Keying edges are event-driven, not periodic, but the interval still bounds
      the latency of the *first* edge after an idle stretch — so this trades against feel
      and needs testing with a real operator, not just a meter.
- [ ] **Measure, then replace the estimates** in the runtime table with real numbers from a
      bench supply or an inline current meter.
- [ ] **Switch the divider with a GPIO** if the ~10 µA it draws through deep sleep turns
      out to matter.

## Open questions

- The charge-sense wire, not yet bench-verified: which LED pad is the cathode net and
  whether that net's high level is 3V3 or VBUS (the 100 kΩ covers either); whether the
  charge LED blinks with a period well under the 3 s window (`CHG_WINDOW_MS`) so that a
  charging cell is never judged solid or dark; and whether a cell that is already full at
  plug-in makes the LED flash at least briefly — if not, such a key stays *unknown* on USB
  rather than showing *charged*, which is the honest fallback the firmware takes.
- Whether BLE + light sleep (keeping the connection alive at much lower current) would be
  worth the complexity compared to the deep sleep + reconnect that is implemented now. Deep
  sleep is simpler, and the app-side reconnect makes the wake invisible apart from the lost
  first press.
- Whether ten minutes is the right idle timeout. Shorter saves little (the connected draw
  is the same whether idle or keying, but ten minutes of it is under 1 % of a cell) and
  risks a sleep inside a slow session; longer only costs battery when the key is forgotten
  switched on.

## Safety

Lithium cells deserve the boring precautions: use a protected cell, never charge
unattended, do not charge a cell that is swollen or has been crushed, and do not seal an
unprotected cell inside a printed case. If the pack gets warm while charging, unplug it and
retire the cell.

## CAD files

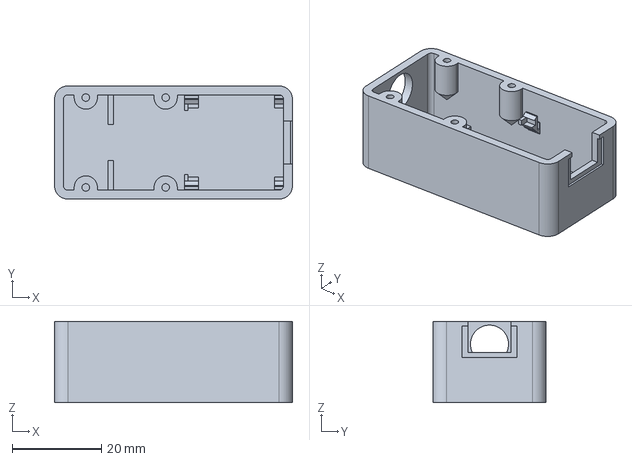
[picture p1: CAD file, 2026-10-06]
enclosure/out/battery-fdm/ble-key-battery-fdm-base.step
53.2 x 25.3 x 18.2 mm

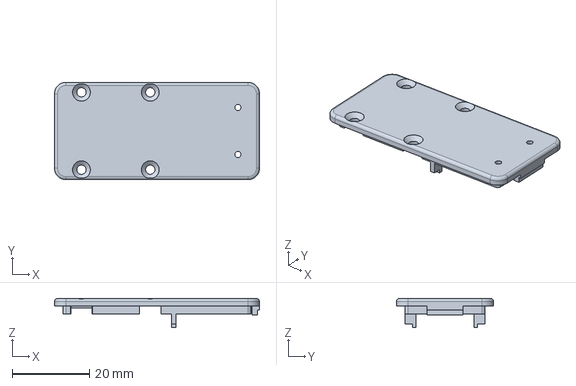
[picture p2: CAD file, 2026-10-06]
enclosure/out/battery/ble-key-battery-lid.step
53.2 x 25.3 x 7.55 mm

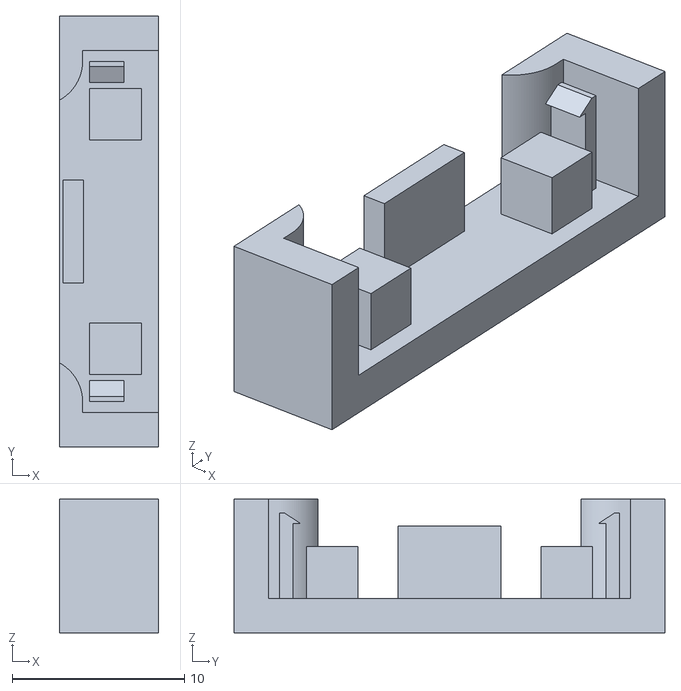
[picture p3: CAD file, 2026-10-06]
enclosure/out/snap-test-fdm/ble-key-snap-test-usb.stl
5.75 x 25.0 x 7.75

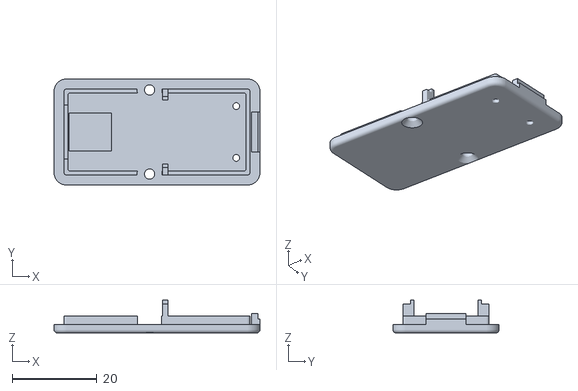
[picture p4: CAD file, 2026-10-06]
enclosure/out/usb-fdm/ble-key-usb-fdm-lid-print.stl
48.5 x 25.0 x 7.75

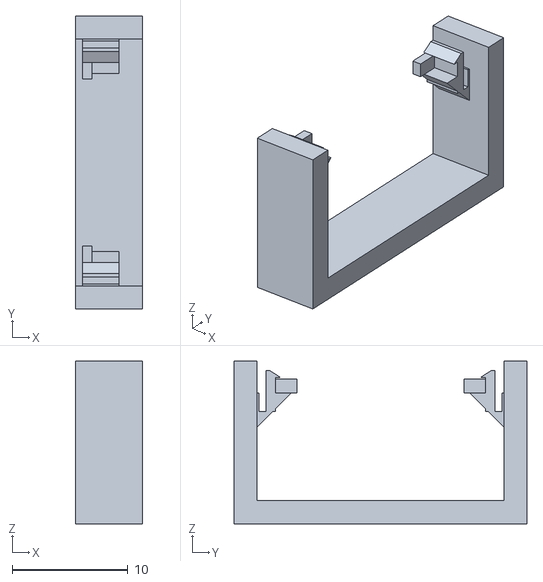
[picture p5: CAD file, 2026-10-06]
enclosure/out/snap-test-fdm/ble-key-snap-test-battery.stl
5.75 x 25.3 x 14.1

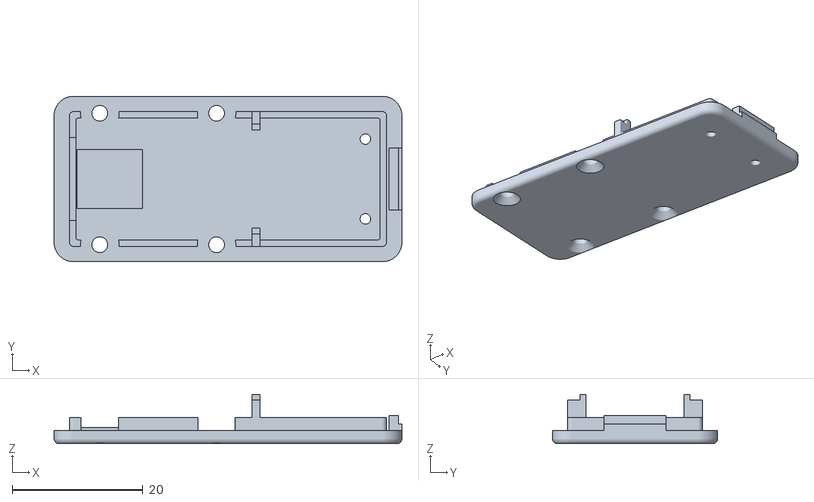
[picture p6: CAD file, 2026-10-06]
enclosure/out/battery-fdm/ble-key-battery-fdm-lid-print.stl
53.2 x 25.3 x 7.55

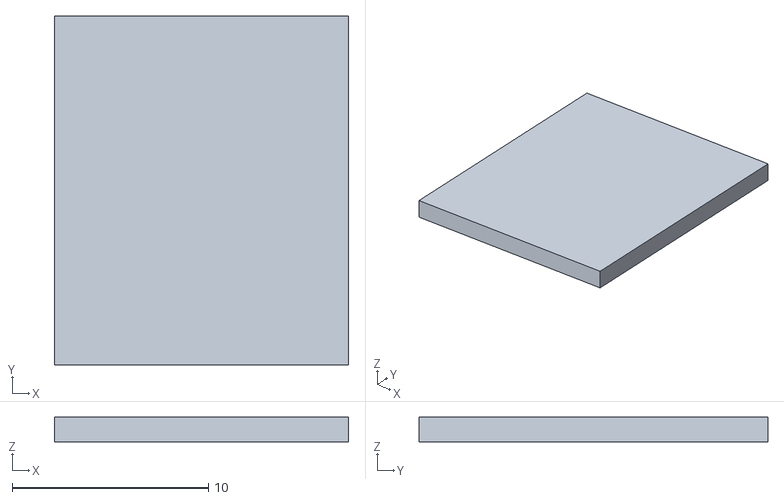
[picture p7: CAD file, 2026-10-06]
enclosure/out/snap-test-fdm/ble-key-snap-test-board.stl
15.0 x 17.8 x 1.25

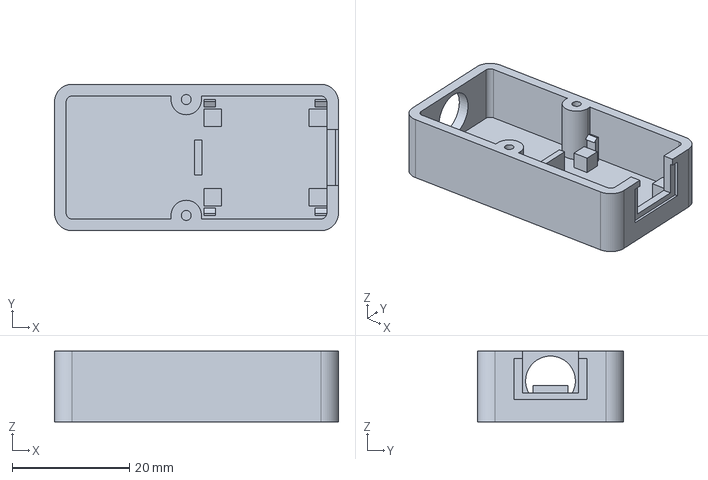
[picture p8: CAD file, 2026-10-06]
enclosure/out/usb-fdm/ble-key-usb-fdm-base.step
48.5 x 25.0 x 12.1 mm

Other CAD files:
enclosure/out/usb/ble-key-usb-lid.step
enclosure/out/battery-fdm/ble-key-battery-fdm-lid.step
enclosure/out/battery/ble-key-battery-base.step
enclosure/out/usb-fdm/ble-key-usb-fdm-lid.step
enclosure/out/usb/ble-key-usb-lid-print.stl
enclosure/out/battery/ble-key-battery-lid-print.stl
enclosure/out/usb/ble-key-usb-base.step
enclosure/out/battery-fdm/ble-key-battery-fdm-base.stl
enclosure/out/battery-fdm/ble-key-battery-fdm-lid.stl
enclosure/out/battery/ble-key-battery-base.stl
enclosure/out/battery/ble-key-battery-lid.stl
enclosure/out/usb-fdm/ble-key-usb-fdm-base.stl
enclosure/out/usb-fdm/ble-key-usb-fdm-lid.stl
enclosure/out/usb/ble-key-usb-base.stl
enclosure/out/usb/ble-key-usb-lid.stl

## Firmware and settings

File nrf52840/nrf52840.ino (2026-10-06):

// Morse key -> BLE (XIAO nRF52840)  — see README.md next to this file
// A BLE interface for a Morse key: plug in your own straight key or paddle and it streams
// the keying as timed edges (5-byte notifications) to the Longpath app, which produces the
// audio/sidetone. The onboard LED gives instant, BLE-independent visual feedback.
//
// Board package: "Seeed nRF52 Boards" (Seeeduino:nrf52, not the mbed one), BLE through its
// bundled Bluefruit library. The board-independent part (UUIDs, packet, debounce, battery
// curve, power states) is in ../lib/BleKeyCore, shared with the ESP32-S3 sketch; ../flash.sh
// passes it to arduino-cli.
//
// Battery: unlike the ESP32-S3, the XIAO nRF52840 brings everything the battery features need,
// so there is no mod beyond soldering a LiPo to the BAT pads:
//   - the cell voltage through an on-board 1 MΩ / 510 kΩ divider into P0.31 (AIN7), switched
//     by P0.14 (VBAT_ENABLE, LOW = on);
//   - USB power from the chip's own VBUS detector (POWER->USBREGSTATUS);
//   - the BQ25100 charger's ~CHG line on P0.17, LOW while a cell charges.
// The Battery Service (0x180F: level 0x2A19 and power state 0x2A1A) is therefore always there.
// Off USB the key can only be running from a cell; on USB without one it publishes the level
// as unknown (0xFF), exactly like the ESP32-S3 key, and the power state stays unknown unless
// the charger says otherwise.
//
// Idle sleep is the nRF52's System OFF (a few µA) with both paddle lines armed as wake-up
// sources. Waking is a reset, as on the ESP32-S3; plugging USB in wakes the key as well.

#include <bluefruit.h>
#include <BleKeyCore.h>
#include <stdarg.h>

// ---- Pins ----
// Same XIAO pads as on the ESP32-S3 key, so the wiring and the case are unchanged.
// Wired as on the ESP32-S3 (D1 and D2 to the jack the same way), yet on the nRF prototype dit
// and dah came out swapped (October 2026), so the nRF reads them the other way round.
const int PIN_DIT      = D2;         // P0.28
const int PIN_DAH      = D1;         // P0.03
const int PIN_KEY_LED  = LED_BLUE;   // P0.06, keying feedback
const int PIN_WARN_LED = LED_RED;    // P0.26, low-battery blink at boot
const int PIN_CHG      = 23;         // P0.17, BQ25100 ~CHG, LOW = charging (no name in the variant)
// PIN_VBAT (P0.31) and VBAT_ENABLE (P0.14) come from the variant.
// The RGB LED is active-low (LOW = on), whatever LED_STATE_ON in the variant says.

// ---- Battery ----
// 1 MΩ over 510 kΩ: a full cell (4.2 V) reads 1.42 V at P0.31, inside the 2.4 V range below.
// The divider is high-impedance (≈340 kΩ source), so the SAADC needs its longest acquisition
// time to settle.
const uint32_t VBAT_DIVIDER_NUM = 1510;
const uint32_t VBAT_DIVIDER_DEN = 510;
const uint32_t ADC_RANGE_MV     = 2400;    // AR_INTERNAL_2_4
const uint32_t ADC_MAX          = 4096;    // 12 bit
const uint8_t  VBAT_SAMPLES     = 16;

BLEService        keySvc(SVC_UUID);
BLECharacteristic evtChar(CHR_UUID);
BLEService        batterySvc(BATTERY_SVC_UUID);
BLECharacteristic batteryChar(BATTERY_LVL_UUID);
BLECharacteristic batteryStateChar(BATTERY_STATE_UUID);
PowerState powerState = POWER_UNKNOWN;   // what the key currently believes, see judgePowerState()

// ---- Logging ----
// Never block on the console. The TinyUSB serial waits as long as the host holds DTR and its
// buffer is full — a monitor that stopped reading would stall the loop and stretch the keying.
// A line that does not fit right now is dropped instead.
void logf(const char* fmt, ...) {
  char buf[160];
  va_list ap;
  va_start(ap, fmt);
  int n = vsnprintf(buf, sizeof(buf), fmt, ap);
  va_end(ap);
  if (n <= 0) return;
  if (n > (int)sizeof(buf) - 1) n = sizeof(buf) - 1;
  if (Serial && Serial.availableForWrite() >= n) Serial.write(buf, n);
}

void sendEvent(Evt e) {
  uint8_t pkt[EVENT_PACKET_LEN];
  encodeEvent(pkt, e, millis());
  evtChar.notify(pkt, sizeof(pkt));   // false while nobody is subscribed — nothing to do then
}

// ---- Battery measurement ----

// Cell voltage in millivolts. Off USB this is the cell; on USB it is the charger's output
// whenever no cell is charging.
uint16_t readBatteryMillivolts() {
  uint32_t sum = 0;
  for (uint8_t i = 0; i < VBAT_SAMPLES; i++) sum += analogRead(PIN_VBAT);
  uint32_t adcMv = (sum / VBAT_SAMPLES) * ADC_RANGE_MV / ADC_MAX;
  return (uint16_t)(adcMv * VBAT_DIVIDER_NUM / VBAT_DIVIDER_DEN);
}

// USB power is present: the nRF52840's own VBUS detector, so a charger or power bank counts
// as much as a host; an enumerated USB connection counts as well, as a second opinion that
// keeps a key on a host from ever sleeping. The register belongs to the SoftDevice once BLE
// runs.
bool usbPowered() {
  if (TinyUSBDevice.mounted()) return true;
  uint32_t status = 0;
  uint8_t sdEnabled = 0;
  sd_softdevice_is_enabled(&sdEnabled);
  if (sdEnabled) sd_power_usbregstatus_get(&status);
  else           status = NRF_POWER->USBREGSTATUS;
  return status & POWER_USBREGSTATUS_VBUSDETECT_Msk;
}

// Push [value] to the client if it differs from what was last published.
static void publishBattery(uint8_t value, const char* why) {
  static int lastPublished = -1;
  if (value == lastPublished) return;
  lastPublished = value;
  batteryChar.write(&value, 1);
  batteryChar.notify(&value, 1);
  logf("[battery] %s\n", why);
}

// Re-measure the cell, and push the level to the client if it changed. Called from loop()
// every VBAT_PERIOD_MS and whenever the power state changes; the first call after boot
// always publishes.
void updateBattery() {
  bool onUsb = usbPowered();
  if (onUsb && powerState != POWER_CHARGING && powerState != POWER_CHARGED) {
    // The pin sees the charger's output now and the key cannot vouch for a cell: no level.
    publishBattery(BATTERY_LEVEL_UNKNOWN, "on USB — level unknown");
    return;
  }

  uint16_t mv = readBatteryMillivolts();
  if (!batteryPlausible(mv)) {
    logf("[battery] implausible reading %u mV — no cell?\n", mv);
    return;
  }

  // While charging this is the cell under charge — a few points high, and climbing; the app
  // shows it as-is next to "charging" and forces 100 % once the key reports charged.
  int percent = batteryPercent(mv);
  char why[48];
  snprintf(why, sizeof(why), "%u mV -> %d %%%s", mv, percent, onUsb ? " (under charge)" : "");
  publishBattery((uint8_t)percent, why);
}

// ---- Charge sense ----

// What the key believes about its power. The BQ25100 pulls ~CHG low for as long as it charges
// a cell and releases it when the cell is full, so: low for whole windows → charging; released
// after having charged → charged. Anything else on USB — released from the start (a full cell,
// or no cell at all) or a flickering line (what the charger does without a cell is not
// verified) — says nothing and stays unknown. Off USB the key runs from the cell, so a
// plausible reading means on cell.
//
// A steady verdict has to hold for CHG_STEADY_WINDOWS windows in a row before it counts.
PowerState judgePowerState(bool onUsb, bool usbJustArrived, bool ledJudged, ChargeLed led) {
  static bool sawCharging = false;   // since USB arrived
  static ChargeLed lastLed = LED_OFF;
  static uint8_t steadyWindows = 0;  // consecutive windows with the same verdict
  if (usbJustArrived) { sawCharging = false; steadyWindows = 0; }

  if (!onUsb) {
    sawCharging = false; steadyWindows = 0;
    return batteryPlausible(readBatteryMillivolts()) ? POWER_ON_CELL : POWER_UNKNOWN;
  }
  if (ledJudged) {
    steadyWindows = (led == lastLed && steadyWindows < 255) ? steadyWindows + 1 : 1;
    lastLed = led;
  }
  bool steady = steadyWindows >= CHG_STEADY_WINDOWS;
  if (lastLed == LED_ON && steady) { sawCharging = true; return POWER_CHARGING; }
  if (sawCharging && lastLed == LED_OFF && steady) return POWER_CHARGED;
  if (sawCharging && lastLed == LED_ON) return POWER_CHARGING;   // still charging, window pending
  return POWER_UNKNOWN;
}

// Push the power state to the client if it changed, and re-run the level, whose meaning on
// USB depends on it (a level is only published while charging or charged).
static void publishPowerState(PowerState ps) {
  if (ps == powerState) return;
  powerState = ps;
  uint8_t value = (uint8_t)ps;
  batteryStateChar.write(&value, 1);
  batteryStateChar.notify(&value, 1);
  logf("[battery] power state: %s\n", powerStateName(ps));
  updateBattery();
}

// BLE-independent low-battery hint at boot: two short red blinks.
void blinkLowBattery() {
  for (int i = 0; i < 2; i++) {
    digitalWrite(PIN_WARN_LED, LOW);  delay(120);
    digitalWrite(PIN_WARN_LED, HIGH); delay(120);
  }
}

// ---- Idle sleep ----

// System OFF until either paddle line goes LOW. Waking is a reset: setup() runs again,
// millis() restarts at 0 and the BLE connection is gone — which is fine, the app re-scans on
// its own, and its keyers detect pauses by wall clock, not device time.
void sleepUntilKeyPress() {
  logf("[sleep] idle — entering System OFF, wake on dit/dah\n");

  // Tell the app now rather than letting it wait for the supervision timeout.
  Bluefruit.Advertising.restartOnDisconnect(false);
  if (Bluefruit.connected()) {
    Bluefruit.disconnect(Bluefruit.connHandle());
    delay(150);                                    // let the disconnect go out
  }
  Bluefruit.Advertising.stop();

  // GPIO configuration survives System OFF: the LEDs stay off (active-low, driven HIGH),
  // VBAT_ENABLE stays LOW, and the pull-ups plus the SENSE setting on the paddle lines are
  // what wakes the chip.
  digitalWrite(PIN_KEY_LED, HIGH);
  digitalWrite(PIN_WARN_LED, HIGH);
  nrf_gpio_cfg_sense_input(g_ADigitalPinMap[PIN_DIT], NRF_GPIO_PIN_PULLUP, NRF_GPIO_PIN_SENSE_LOW);
  nrf_gpio_cfg_sense_input(g_ADigitalPinMap[PIN_DAH], NRF_GPIO_PIN_PULLUP, NRF_GPIO_PIN_SENSE_LOW);
  delay(5);

  uint8_t sdEnabled = 0;
  sd_softdevice_is_enabled(&sdEnabled);
  if (sdEnabled) sd_power_system_off();
  else           NRF_POWER->SYSTEMOFF = 1;
  while (true) {}                                  // not reached
}

// ---- Link ----

// The callbacks run in Bluefruit's callback task; they only record what happened, and loop()
// does the logging, so the USB serial is only ever written from one task.
volatile uint32_t connectedAtMs = 0;      // for the one-off parameter log in loop()
volatile bool     connectSeen = false;
volatile int      disconnectReason = -1;

void logConnParams(const char* when) {
  if (!Bluefruit.connected()) return;
  BLEConnection* conn = Bluefruit.Connection(Bluefruit.connHandle());
  if (!conn) return;
  uint32_t interval = conn->getConnectionInterval() * 125;   // × 1.25 ms, in 1/100 ms
  logf("[paddle] link %s: interval %lu.%02lu ms, latency %u, timeout %u ms\n", when,
       interval / 100, interval % 100, conn->getSlaveLatency(), conn->getSupervisionTimeout() * 10);
}

void onConnect(uint16_t connHandle) {
  Bluefruit.Connection(connHandle)->requestConnectionParameter(CONN_INTERVAL_MIN, CONN_LATENCY, CONN_TIMEOUT);
  connectedAtMs = millis();
  connectSeen = true;
}

// Bluefruit re-advertises on its own after a disconnect (restartOnDisconnect), so the app can
// reconnect without power-cycling the board.
void onDisconnect(uint16_t connHandle, uint8_t reason) {
  disconnectReason = reason;
}

// Which paddle woke the chip: the GPIO LATCH register keeps the pins whose SENSE condition
// was met. Read before pinMode() reconfigures the pins.
static bool wokeFromSleep = false;
static bool wokeOnDah = false;

void setup() {
  uint32_t latch = NRF_P0->LATCH;
  NRF_P0->LATCH = latch;                           // write-1-to-clear
  wokeFromSleep = readResetReason() & POWER_RESETREAS_OFF_Msk;
  wokeOnDah = latch & (1UL << g_ADigitalPinMap[PIN_DAH]);

  Serial.begin(115200);
  // Woken by a key press? Then every millisecond counts towards the reconnect — skip the
  // serial-monitor grace period a cold boot affords.
  if (!wokeFromSleep) delay(400);
  if (wokeFromSleep) logf("\n[paddle] woke on key press (%s)\n", wokeOnDah ? "dah" : "dit");
  else               logf("\n[paddle] boot (reset reason 0x%08lx)\n", readResetReason());

  pinMode(PIN_DIT, INPUT_PULLUP);                  // also clears the SENSE setting of the sleep
  pinMode(PIN_DAH, INPUT_PULLUP);
  pinMode(PIN_KEY_LED, OUTPUT);
  digitalWrite(PIN_KEY_LED, HIGH);                     // off (active-low)
  pinMode(PIN_WARN_LED, OUTPUT);
  digitalWrite(PIN_WARN_LED, HIGH);
  logf("[paddle] pins ready\n");

  // The variant parks VBAT_ENABLE HIGH. Seeed's advice is the opposite: with it HIGH, a full
  // cell lifts P0.31 above VDD through the divider. LOW for good costs ~3 µA through the
  // divider and keeps the pin safe, in System OFF as well.
  pinMode(VBAT_ENABLE, OUTPUT);
  digitalWrite(VBAT_ENABLE, LOW);
  pinMode(PIN_CHG, INPUT_PULLUP);
  analogReference(AR_INTERNAL_2_4);
  analogReadResolution(12);
  analogSampleTime(40);
  if (usbPowered()) {
    logf("[battery] on USB — idle sleep off, watching ~CHG\n");
  } else {
    uint16_t bootMv = readBatteryMillivolts();
    logf("[battery] %u mV at boot (%d %%)\n", bootMv, batteryPercent(bootMv));
    if (bootMv < VBAT_LOW_MV) blinkLowBattery();
  }

  Bluefruit.autoConnLed(false);                    // the LED belongs to the keying
  Bluefruit.begin();
  Bluefruit.setName(DEVICE_NAME);
  Bluefruit.Periph.setConnInterval(CONN_INTERVAL_MIN, CONN_INTERVAL_MAX);
  Bluefruit.Periph.setConnSlaveLatency(CONN_LATENCY);
  Bluefruit.Periph.setConnSupervisionTimeout(CONN_TIMEOUT);
  Bluefruit.Periph.setConnectCallback(onConnect);
  Bluefruit.Periph.setDisconnectCallback(onDisconnect);
  uint8_t mac[6];
  Bluefruit.getAddr(mac);
  logf("[paddle] BLE MAC: %02X:%02X:%02X:%02X:%02X:%02X\n", mac[5], mac[4], mac[3], mac[2], mac[1], mac[0]);

  keySvc.begin();
  evtChar.setProperties(CHR_PROPS_NOTIFY);
  evtChar.setPermission(SECMODE_OPEN, SECMODE_NO_ACCESS);
  evtChar.setFixedLen(EVENT_PACKET_LEN);
  evtChar.begin();

  // Standard Battery Service: the client reads the level once after connecting and then
  // subscribes to changes. Seeded with "unknown" until the first updateBattery() below
  // replaces it (the first call always publishes).
  batterySvc.begin();
  BLECharacteristic* batteryChars[] = { &batteryChar, &batteryStateChar };
  for (BLECharacteristic* chr : batteryChars) {
    chr->setProperties(CHR_PROPS_READ | CHR_PROPS_NOTIFY);
    chr->setPermission(SECMODE_OPEN, SECMODE_NO_ACCESS);
    chr->setFixedLen(1);
    chr->begin();
  }
  uint8_t seed = BATTERY_LEVEL_UNKNOWN;
  batteryChar.write(&seed, 1);
  uint8_t stateSeed = POWER_UNKNOWN;
  batteryStateChar.write(&stateSeed, 1);
  bool onUsb = usbPowered();
  publishPowerState(judgePowerState(onUsb, onUsb, false, LED_OFF));
  updateBattery();

  // Flags and the 128-bit Longpath UUID fill the advertising packet; the name goes into the
  // scan response. The app scans for the Longpath service only.
  Bluefruit.Advertising.addFlags(BLE_GAP_ADV_FLAGS_LE_ONLY_GENERAL_DISC_MODE);
  Bluefruit.Advertising.addService(keySvc);
  Bluefruit.ScanResponse.addName();
  Bluefruit.Advertising.restartOnDisconnect(true);
  Bluefruit.Advertising.setInterval(32, 244);      // × 0.625 ms: 20 ms fast, then 152.5 ms
  Bluefruit.Advertising.setFastTimeout(30);        // seconds of fast advertising
  bool ok = Bluefruit.Advertising.start(0);        // 0 = forever
  logf("[paddle] advertising started: %s\n", ok ? "yes" : "NO");
}

void loop() {
  static Debounced dit, dah;
  static uint32_t lastBatteryMs = 0;
  static uint32_t lastEdgeMs = 0;                   // boot counts as activity
  static bool readyLogged = false;
  static bool wasOnUsb = usbPowered();
  static bool onUsb = wasOnUsb;
  static uint32_t lastVbusMs = 0;
  static ChargeLedWatch chargeLed;

  uint32_t now = millis();

  // The serial monitor misses everything printed before it attaches, i.e. the whole boot
  // log after a wake. Repeat the essentials once the monitor has had a chance to attach.
  if (!readyLogged && now >= 3000) {
    readyLogged = true;
    logf("[paddle] ready — %s, %s\n",
         wokeFromSleep ? (wokeOnDah ? "woke on dah" : "woke on dit") : "cold boot",
         Bluefruit.connected() ? "connected" : "advertising");
    logf("[battery] BAT %u mV — %s, power state %s\n", readBatteryMillivolts(),
         usbPowered() ? "on USB, idle sleep off" : "on the cell", powerStateName(powerState));
  }
  if (connectSeen) { connectSeen = false; logConnParams("at connect"); }
  if (disconnectReason >= 0) {
    logf("[paddle] central disconnected (reason 0x%02x) — re-advertising\n", disconnectReason);
    disconnectReason = -1;
  }
  // Log the negotiated link parameters once, a few seconds after the connect (the central
  // answers the update request asynchronously).
  if (connectedAtMs && (now - connectedAtMs) >= 3000) {
    connectedAtMs = 0;
    logConnParams("settled");
  }

  bool ditSample = (digitalRead(PIN_DIT) == LOW);  // pressed = LOW
  bool dahSample = (digitalRead(PIN_DAH) == LOW);

  if (dit.update(ditSample, now)) {
    sendEvent(dit.reported ? DIT_DOWN : DIT_UP);
    logf(dit.reported ? "[paddle] DIT down\n" : "[paddle] DIT up\n");
    lastEdgeMs = now;
  }
  if (dah.update(dahSample, now)) {
    sendEvent(dah.reported ? DAH_DOWN : DAH_UP);
    logf(dah.reported ? "[paddle] DAH down\n" : "[paddle] DAH up\n");
    lastEdgeMs = now;
  }

  bool keyed = dit.reported || dah.reported;        // debounced state drives the LED
  digitalWrite(PIN_KEY_LED, keyed ? LOW : HIGH);        // active-low

  // Measured only while the key is idle: the 16-sample ADC burst at 40 µs each takes about a
  // millisecond and must not land between two paddle edges.
  if (!keyed && (now - lastBatteryMs) >= VBAT_PERIOD_MS) {
    lastBatteryMs = now;
    // Off USB the cell speaks for itself; re-judge with every measurement.
    if (!onUsb) publishPowerState(judgePowerState(false, false, false, LED_OFF));
    updateBattery();
  }

  // USB presence is a register read, but is still only re-sampled once a second so a plug
  // that bounces does not reset the charge classifier several times.
  bool usbJustArrived = false;
  if ((now - lastVbusMs) >= VBUS_PERIOD_MS) {
    lastVbusMs = now;
    onUsb = usbPowered();
    if (onUsb != wasOnUsb) {
      logf(onUsb ? "[battery] USB power present\n" : "[battery] USB power gone\n");
      usbJustArrived = onUsb;
      if (!onUsb) publishPowerState(judgePowerState(false, false, false, LED_OFF));
    }
  }

  // ~CHG is cheap to sample, so it is watched on every pass; its verdict, once a window, is
  // what moves the power state while on USB.
  bool ledJudged = chargeLed.sample(digitalRead(PIN_CHG) == LOW, now);
  if (onUsb && (ledJudged || usbJustArrived)) {
    publishPowerState(judgePowerState(true, usbJustArrived, ledJudged, chargeLed.verdict));
  }

  // No idle sleep on USB: there is nothing to save and a sleep would cost the first press
  // (and drop the serial port). Unplugging restarts the idle clock, so a key taken off the
  // charger stays awake for a full idle period first.
  if (wasOnUsb && !onUsb) lastEdgeMs = now;
  wasOnUsb = onUsb;

  // Idle long enough → sleep. Never while a paddle is held: a held line is LOW and would
  // wake the chip again immediately (and a key left resting on its contact should keep the
  // LED on, which is the visible hint that something is wrong).
  if (!onUsb && !keyed && (now - lastEdgeMs) >= IDLE_SLEEP_MS) {
    sleepUntilKeyPress();                           // does not return
  }
}

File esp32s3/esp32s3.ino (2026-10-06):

// Morse key -> BLE (XIAO ESP32-S3)  — see README.md next to this file
// A BLE interface for a Morse key: plug in your own straight key or paddle and it streams
// the keying as timed edges (5-byte notifications) to the Longpath app, which produces the
// audio/sidetone. The onboard LED gives instant, BLE-independent visual feedback.
//
// Library: NimBLE-Arduino  ->  arduino-cli lib install "NimBLE-Arduino"
// The board-independent part (UUIDs, packet, debounce, battery curve, power states) is in
// ../lib/BleKeyCore, shared with the nRF52840 sketch; ../flash.sh passes it to arduino-cli.
//
// Battery (optional mod, see BATTERY.md): a LiPo on the BAT pads plus a 2 × 220 kΩ divider
// from BAT+ to GND, tapped into A0. The cell level is published through the SIG-standard
// Battery Service (0x180F / 0x2A19) next to the Longpath service — the keying contract is
// untouched, and clients that do not know the service simply ignore it. A battery key also
// deep-sleeps after IDLE_SLEEP_MS without a paddle edge and wakes on the next press
// (14 µA instead of tens of mA); the press that wakes it is consumed by the boot.
//
// On USB neither makes sense: BAT+ is the charger's output and reads ~3.9–4.2 V whether a cell
// is fitted or not, and a sleep would only cost the first press. So while USB power is present
// the key publishes BATTERY_LEVEL_UNKNOWN (0xFF) instead of a percentage — the Longpath app
// shows no level for it — and the idle sleep is off. USB power is sensed on the 5V pin (VBUS)
// through a second 2 × 220 kΩ divider into D10, so a plain charger or power bank counts too;
// a USB host (serial) is detected as well, as a fallback for a key without that divider.
//
// Charge sense (optional, on top of the battery mod): the XIAO's charge IC drives the red
// charge LED and nothing else — solid for ~30 s after USB arrives without a cell, flashing
// while a cell charges, off once it is full. One wire from that LED's net (the IC's open-drain
// status output, LOW = LED on) into D3 lets the firmware read it. The key then also exposes
// the SIG Battery Power State characteristic (0x2A1A: on cell / charging / charged / no cell)
// and keeps publishing the live level while charging, so the Longpath app can say
// "78 % · charging" and "100 % · charged". Without the wire the pin reads "off" forever, the
// classifier has no evidence, and the key reports the power state as unknown — the app then
// shows the plain connected chip on USB, exactly as before. One build fits every key.

#include <NimBLEDevice.h>
#include <BleKeyCore.h>
#include <esp_sleep.h>
#include <driver/rtc_io.h>
#include <driver/gpio.h>

// ---- Pins ----
const int PIN_DIT   = D1;   // GPIO2, Tip
const int PIN_DAH   = D2;   // GPIO3, Ring
const int PIN_VBAT  = A0;   // GPIO1, battery divider tap (BATTERY_MOD only)
const int PIN_VBUS  = D10;  // GPIO9, USB-power (5V pin) divider tap (BATTERY_MOD only)
const int PIN_CHG   = D3;   // GPIO4, charge-LED net tap, LOW = LED on (charge-sense wire only)
// LED_BUILTIN = GPIO21 on the XIAO, active-low (LOW = on, HIGH = off)

// ---- Battery ----
// 1 = the battery code is compiled in and the key checks at boot whether the mod is actually
//     fitted (see detectBatteryMod): with it, the level is reported over BLE and the key
//     deep-sleeps when idle; without it — a stock USB key, both divider taps floating — the
//     Battery Service is not created and the key never sleeps, so one build fits every key.
// 0 = compile the battery code out entirely (no ADC, no sleep, smaller image):
//   arduino-cli compile --build-property "compiler.cpp.extra_flags=-DBATTERY_MOD=0" ...
#ifndef BATTERY_MOD
#define BATTERY_MOD 1
#endif

// The divider halves the cell voltage (220 kΩ over 220 kΩ), which keeps a full cell
// (4.2 V → 2.1 V) inside the ADC range at 11 dB attenuation (~0–3.1 V). The VBUS divider is
// the same 1:1 pair: 5 V → 2.5 V.
const float    VBAT_DIVIDER   = 2.0f;
const float    VBUS_DIVIDER   = 2.0f;
const uint16_t VBUS_PRESENT_MV = 4000;   // above this the 5V pin carries USB power
const uint8_t  VBAT_SAMPLES   = 16;      // oversampling — the ESP32 ADC is noisy

NimBLECharacteristic* evtChar          = nullptr;
NimBLECharacteristic* batteryChar      = nullptr;
NimBLECharacteristic* batteryStateChar = nullptr;
bool batteryModFitted = false;   // decided once at boot by detectBatteryMod()
PowerState powerState = POWER_UNKNOWN;   // what the key currently believes, see judgePowerState()

// 5-byte little-endian packet: [event][uint32 millis timestamp]
void sendEvent(Evt e) {
  uint8_t pkt[EVENT_PACKET_LEN];
  encodeEvent(pkt, e, millis());
  evtChar->setValue(pkt, sizeof(pkt));
  evtChar->notify();
}

// ---- Battery measurement ----

// Cell voltage in millivolts, from the calibrated ADC reading at the divider tap.
uint16_t readBatteryMillivolts() {
  uint32_t sum = 0;
  for (uint8_t i = 0; i < VBAT_SAMPLES; i++) sum += analogReadMilliVolts(PIN_VBAT);
  return (uint16_t)((sum / VBAT_SAMPLES) * VBAT_DIVIDER);
}

// USB power on the 5V pin, in millivolts, from the divider tap on D10.
uint16_t readVbusMillivolts() {
  uint32_t sum = 0;
  for (uint8_t i = 0; i < VBAT_SAMPLES; i++) sum += analogReadMilliVolts(PIN_VBUS);
  return (uint16_t)((sum / VBAT_SAMPLES) * VBUS_DIVIDER);
}

// USB power is present: VBUS is up (charger, power bank or host), or a USB host is talking to
// the serial port (fallback for a key without the VBUS divider — then D10 floats low-ish).
bool usbPowered() {
  return readVbusMillivolts() >= VBUS_PRESENT_MV || Serial.isPlugged();
}

// Is the battery mod actually on this board? With the mod, at least one of the two divider
// taps reads something real at boot: VBUS ≥ 4 V (the key is on USB) or a plausible cell
// voltage on A0. On a stock key both pins float, and a floating ADC input is noisy — so the
// reading has to hold across a few samples spread over ~50 ms before it counts.
bool detectBatteryMod() {
  bool vbusAll = true, cellAll = true;
  for (int i = 0; i < 5; i++) {
    if (readVbusMillivolts() < VBUS_PRESENT_MV) vbusAll = false;
    if (!batteryPlausible(readBatteryMillivolts())) cellAll = false;
    delay(10);
  }
  return vbusAll || cellAll;
}

// Push [value] to the client if it differs from what was last published.
static void publishBattery(uint8_t value, const char* why) {
  static int lastPublished = -1;
  if (value == lastPublished) return;
  lastPublished = value;
  batteryChar->setValue(&value, 1);
  batteryChar->notify();
  Serial.printf("[battery] %s\n", why);
}
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

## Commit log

2026-07-03 Initial commit: BLE Morse key firmware for XIAO ESP32-S3
    Reads an iambic paddle (dit/dah), debounces the contacts, and streams
    timed paddle edges over BLE as 5-byte little-endian notifications
    ([event][uint32 millis]). Drives a local piezo sidetone and the onboard
    LED for BLE-independent feedback. Re-advertises on disconnect.
    Includes flash.sh / monitor.sh helpers (arduino-cli, XIAO ESP32-S3).
2026-07-03 Remove piezo sidetone; the device is only the BLE key interface
    The device makes no sound — students plug in their own straight key or
    paddle and it streams keying edges over BLE to the Sidetone app, which
    produces the audio/sidetone. Drop the piezo pin, LEDC setup, and tone
    output; keep the debug LED. Reframe README and header comment accordingly.
2026-08-17 Rename the companion app from Sidetone to Longpath
    The Morse-training app this firmware streams to was renamed after a name collision
    in the App Store. The README link now points at the public product page rather than
    the app's repository, which is private — a public README should not link somewhere
    only its author can open.
    The lowercase "audio/sidetone" stays in both files: there it means the audible
    monitoring tone the app produces, not the product.
    [ble-key.ino]
2026-08-23 docs: the UUIDs are the fixed Longpath contract, not placeholders
    The "replace with uuidgen" instruction predates the key being a
    product: now that self-built, kit, and ready-made keys all target the
    Longpath app — which ships these exact UUIDs — regenerating them would
    build a key the app cannot find. Keep them; minting a fresh pair is
    only for forks that speak to a different client.
    Claude-Session: https://claude.ai/code/session_01MCrJ1rE6ixNCMzjDbVCxgG
    [ble-key.ino]
2026-08-24 docs: add a wiring diagram
    Fritzing-style SVG: XIAO ESP32-S3 to the 3.5 mm TRS jack — D1/tip
    (dit), D2/ring (dah), GND/sleeve — plus the plug pinout and the
    no-resistors note, so the Hardware table has a picture to match.
    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
2026-08-24 docs: draw the TRS jack the way a panel socket actually looks
    The first attempt read as a camera module. Now it is the standard side
    view — three solder lugs, body, mounting nut, threaded bushing and the
    plug opening — with the lug names sitting on the body so no wire can
    cross them.
    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
2026-08-24 docs: land the GND wire on the sleeve lug
    It approached the socket from the right and disappeared behind the
    body — the solder lugs are on the left. Now it runs above the socket
    and down its left side, ending on the sleeve lug like the other two.
    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
2026-09-02 feat: sense USB power on D10, tight link params, no level on USB
    A key on USB power reported the charger's output on BAT+ as a cell
    level ("62 %" with no cell fitted). A second 2 x 220 kOhm divider from
    the 5V pin (USB VBUS) into D10 now tells the firmware when USB power is
    present - host, charger or power bank alike; a USB host on the serial
    port counts as a fallback for a key without the divider. On USB the key
    publishes 0xFF (level unknown) instead of a percentage and skips the
    idle sleep; unplugging restarts the idle clock.
    Keying edges must not wait for a skipped connection event: on connect
    the key now requests a 15-30 ms interval with no slave latency and logs
    the parameters the cent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
    [ble-key.ino]
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2026-09-02 feat: detect the battery mod at boot so one build fits every key
    A stock key flashed with the battery build read noise on the floating
    divider taps: random percentages, a random low-battery blink, and a
    pointless deep sleep on a power bank. The firmware now decides at boot
    whether the mod is fitted - VBUS on D10, or a plausible cell voltage on
    A0, steady over a few samples - and otherwise creates no Battery Service
    and never sleeps. BATTERY_MOD is overridable from the build command to
    compile the battery code out entirely.
    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
    [ble-key.ino]
2026-09-02 fix: never block on the USB serial console
    After a serial monitor closes the port the native USB serial still
    sees the host's DTR, treats the console as connected, and every print
    then blocks until its write times out. loop() stalled for two seconds
    after each paddle edge, so the release edge was stamped two seconds
    late and the app heard a stream of dits or dahs. This is what made the
    "many dits" reports come and go all day: they appeared whenever a
    monitor had been opened and closed, and vanished while one was reading.
    A zero TX timeout makes a full buffer drop instead of block.
    Claude-Session: https://claude.ai/code/session_01Kp576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
    [ble-key.ino]
2026-09-02 fix: debounce paddle edges for 12 ms
    A paddle's contacts bounced for 6 ms (down, up, down within 13 ms in the
    app's event log), which the 5 ms debounce let through as a stray edge.
    12 ms is still far below a 30 ms dit at 40 WPM.
    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
    [ble-key.ino]
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2026-09-03 docs: draw the charge-sense wire in the wiring diagram
    A third strip shows the USB-C end of the XIAO from the top: the red
    charge LED beside the jack on the RESET side, its cathode pad through
    100 kOhm into D3, with the LED's meaning (flashing = charging, dark =
    full, solid ~30 s = no cell). The main drawing marks the CHG LED and D3;
    README and BATTERY.md point at the strip.
    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
2026-10-01 feat: printable housing for the XIAO and the paddle jack
    A build123d script that builds a base and a screwed-on lid in two versions:
    USB-only, and one with a compartment for the 350 mAh LP-552035 cell. Both
    take a PJ-392 panel jack and clamp the board between corner pads and the lid
    without screws. STEP and STL for every part are in enclosure/out/, and
    preview.html shows a rotatable 3D preview after running the script.
    [ble-key-battery-base.step, ble-key-battery-base.stl, ble-key-battery-lid-print.stl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]
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2026-10-01 feat: schematic for the nRF52840 board
    A generated KiCad 10 schematic for the custom board from PCB-PLAN.md: Raytac
    MDBT50Q-1MV2, BQ24074 charger with power path, USB-C with ESD protection,
    the 3.5 mm paddle jack, a JST-PH battery socket, Feather-compatible LEDs and
    reset, and Tag-Connect SWD pads. Values follow the Raytac and TI datasheets;
    ERC passes with no errors.
    [ble-key-bom.csv, ble-key.kicad_sch]
2026-10-01 feat: first routed layout of the nRF52840 board
    46 x 26 mm, 2 layers, AISLER 2-layer ENIG rules. gen_board.py places the
    footprints from the schematic's netlist and adds the outline, mounting
    holes, ground pours and an antenna keep-out; route.py autoroutes with
    Freerouting in Docker and refills the pours. DRC: no errors, no unconnected
    pads. Dah and the charge signal moved to outer module pads, passives to 0402.
    [ble-key-bom.csv, ble-key.kicad_pcb, ble-key.kicad_sch]
2026-10-01 fix: stitch the board's ground pours and give the charger room
    Ground is routed first so every pad has a real connection, then a grid of
    stitching vias ties the two pours together and extra vias join patches that
    traces cut off. The charger's exposed pad gets thermal vias and the ESD chip a
    ground dog-bone. The board grows to 48 x 27 mm so the charger corner can be
    routed. DRC: no errors, no unconnected pads.
    [ble-key.kicad_pcb]
2026-10-01 feat: printable case for the nRF52840 board, USB-only and with battery
    board_case.py builds a base and a lid around the custom board from the
    board's exported STEP and mechanics.json: two M2 x 8 screws clamp the board
    between them, the lid arches over USB-C and the jack, a flexible tongue
    reaches the reset switch and a light channel carries the status LEDs. The
    battery version holds the LP-552035 in a lid pocket above the board.
    The board changes to fit: the JST plug points inward, the LEDs move to the
    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
    [ble-key-board-battery-base.step, ble-key-board-battery-base.stl, ble-key-board-battery-lid-print.stl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]
2026-10-01 feat: part numbers for the crystal, its capacitors and the DC/DC inductor
    Y1 Epson FC-12M (CL 9 pF, matched to the 12 pF capacitors per Nordic's
    guidance), C9/C10 Murata GRM1555C1H120GA01D, L1 Taiyo Yuden LBMF1608T100K as
    on the nRF52840-DK. The board's footprints now carry the MPN field too, so
    AISLER can match parts from the layout file.
    [ble-key-bom.csv, ble-key.kicad_pcb, ble-key.kicad_sch]
2026-10-01 docs: real AISLER quote and cost drivers in the PCB plan
    Assembled boards cost 47.44 EUR each at 30 (1,423.21 EUR net). Parts as
    AISLER buys them are about twice their list price and assembly setup is
    mostly fixed per order; the module is the largest single part. Lists ways
    to cut the cost: larger runs, fewer different parts, supplying the module.
2026-10-01 feat: JLCPCB production files with LCSC part numbers
    export_jlc.py writes zipped Gerbers and drill files, a BOM in JLCPCB's format
    and a placement file from the board, with the LCSC part numbers now stored in
    the schematic. The module and the reset switch are out of stock at JLCPCB.
    [ble-key-bom.csv, ble-key.kicad_sch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]
2026-10-01 docs: JLCPCB quote and the jack's rotation fix for their placement
    30 assembled boards cost 264.84 USD at JLCPCB without the module and the
    reset switch, which they have no stock of. The SJ-3523 jack needs a 270
    degree correction in the placement file to match JLCPCB's part model.
    [ble-key-cpl.csv]
2026-10-01 feat: Seeed Fusion PCBA files (BOM with MPNs and the module's Seeed SKU)
    [ble-key-bom.csv, ble-key-pnp.csv]
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2026-10-01 fix: XIAO housings fit the XIAO nRF52840 as well as the ESP32-S3
    The lid's hold-down pins landed on a small part of the XIAO nRF52840; they
    are now thinner and sit closer to the board corners, on bare board on both
    boards. Seeed's nRF52840 model is added and checked: no overlap with either
    housing.
    [ble-key-battery-base.step, ble-key-battery-lid-print.stl, ble-key-battery-lid.step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]
2026-10-01 feat: FDM print files for the XIAO cases (PETG, 0.35 mm fit)
    enclosure.py --fdm writes out/usb-fdm/ and out/battery-fdm/ with a looser fit
    for FDM printing; the README gives print settings for a Bambu Lab A1 mini.
    [ble-key-battery-fdm-base.step, ble-key-battery-fdm-base.stl, ble-key-battery-fdm-lid-print.stl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]
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2026-10-02 fix: countersunk screw holes in the XIAO lids
    The 2 mm lids had a 1.2 mm deep flat counterbore for pan heads, leaving 0.8 mm
    under the head. They now have 90 degree countersinks for 2.2 mm countersunk
    screws (DIN 7982): more lid material under the head, the load spread over the
    cone, self-centring and flush. MJF and FDM files regenerated.
    [ble-key-battery-base.step, ble-key-battery-fdm-base.step, ble-key-battery-fdm-lid.step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]
2026-10-03 fix: XIAO lids had a 5.7 mm hole through each screw position
    The cut that frees the lid's alignment lip around the screw bosses was as tall
    as the whole case, so it went through the lid plate and took the countersink
    with it. It is now only as tall as the lip; the lids have the intended 90
    degree countersink over a 2.4 mm hole and rest on the bosses again. MJF and
    FDM files regenerated; the preview reloads the meshes without the cache.
    [ble-key-battery-base.step, ble-key-battery-fdm-base.step, ble-key-battery-fdm-lid-print.stl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]
2026-10-06 feat: XIAO nRF52840 firmware; split the repo by board
    The key now runs on the XIAO nRF52840 as well as the ESP32-S3, with the
    same BLE contract. The nRF52840 reads battery, charge state and USB power
    from the board itself, so a LiPo is the only battery mod, and idle sleep
    is System OFF with wake on dit or dah.
    Layout: esp32s3/ and nrf52840/ hold each board's sketch and docs (the
    custom nRF52840 PCB moves to nrf52840/pcb/), lib/BleKeyCore is the shared
    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
    [ble-key-bom.csv, ble-key-pnp.csv, ble-key.kicad_pcb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]
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2026-10-06 feat: XIAO battery case with the cell under the board; snap-in board
    Battery case: the LP-552035 lies on the floor, a 3 mm wiring layer sits
    above it for the BAT joints and the paddle wires soldered to the board's
    underside, and the XIAO rests on 45° wall brackets on top. The jack moves
    up over the cell, with a bay for the JST-PH pair and spare lead under it;
    the screw bosses hang from the walls. 53.2 x 25.3 x 19.2 mm instead of
    43 x 48 x 13.6 mm.
    Both XIAO cases: the board clicks in on four springy snap lips that hook
    over its long edges, and the lid presses the far corners with stiff
    L-shaped ribs instead of thin pins.
    [ble-key-battery-base.step, ble-key-battery-base.stl, ble-key-battery-fdm-base.step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]
2026-10-06 feat: snap-lip test pieces, shown on the preview page; drop the custom nRF board
    enclosure.py --snap-test writes two short FDM slices of the XIAO cases
    (USB and battery) around the board's far supports, plus a board stand-in,
    so the snap lips can be tried in minutes before printing a whole case.
    The preview page shows them in 3D and explains how to print and test
    them.
    The plan for an own nRF52840 board is dropped: its KiCad project, plan,
    quotes and case (board_case.py) are removed, and the page only offers
    the XIAO cases.
    [ble-key-board-battery-base.step, ble-key-board-battery-base.stl, ble-key-board-battery-lid-print.stl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]
2026-10-06 feat: case for the Cliff FC681374V jack (Reichelt), PJ-392 still selectable
    The XIAO cases now default to the Cliff FC681374V: M8 thread through an
    8.5 mm hole in the full wall, ring nut outside, square body inside held
    flat by a block under the lid so the nut cannot turn it. The USB case
    grows to 48.5 x 25.0 x 14.1 mm, the battery case to 20.2 mm high.
    --jack pj392 reproduces the previous cases exactly.
    [ble-key-battery-base.step, ble-key-battery-base.stl, ble-key-battery-fdm-base.step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]
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2026-10-06 fix(nrf52840): read dit on D2 and dah on D1
    Wired as on the ESP32-S3, the nRF prototype reported dit and dah swapped.
    [nrf52840.ino]
2026-10-16 feat: battery case with a drop-in frame; jack slot; bigger snap hooks
    The cell now goes in and out straight from above: everything that held
    the board and the screws hung over it, so the base became a tray with a
    cell pocket and shoulders, and a separate frame drops in on top of the
    cell. It carries the board brackets, the snap lips, the screw bosses and
    a cradle for the jack; the lid's screws clamp it. Rails with an outer
    web, a cross wall at the USB end, a middle cross bar and the cradle make
    it stiff.
    The jack hole in both cases is a slot open to the top, closed by a lid
    tab, so board, jack and frame go in as one module with everything
    soldered directly. The lid block on the jack is gone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
2026-10-16 feat(jig): stiffer, wider clips and a longer plate for the XIAO soldering jig
    Clips 1.2 mm thick on wide bodies beyond the board so they do not wobble,
    hooks up to 0.8 mm with a flat tip, an 8 mm hook over the USB-C shell, and an
    80 mm plate. STEP and STL regenerated.
2026-10-24 feat(jig): rigid USB-C holder and a sturdier far clip
    The first jig broke: both holders were 1.2 mm springy tongues with sharp
    roots, printed upright, so they bent across the layers and snapped.
    The USB end is now a rigid 3 mm block with a gusset, joined to the
    centring posts; the board goes in tilted, socket first, and clicks in at
    the far end. The far clip is 1.6 mm thick, 16 mm wide and gusseted at
    its root. The board sits 5 mm above the plate (was 3 mm), which gives the
    thicker clip enough spring and the iron more room underneath.
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2026-10-24 feat(enclosure): screw the battery case's lid to the base, in its corners
    The lid's screws went into bosses on the drop-in frame, so they clamped
    lid and frame together but held nothing to the case. Now a boss hangs in
    each of the base's four corners from the top (6.5 mm deep, 5.5 mm pilot,
    a 45° slope below so it prints without supports) and the same four
    2.2 x 6.5 countersunk screws go into them. The frame loses its bosses,
    is cut away round the corner bosses and is held down by the lid through
    the board.
    The case is 3 mm wider (53.2 x 30.5 x 21.1 mm), so the bosses at the USB
    end stand clear beside the board. The snap lips at that end move in to
    6.7 mm, between the second and third pad,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
2026-10-24 docs(enclosure): preview page for the corner-screwed battery case; new frame snap test
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2026-10-25 fix(nrf52840): read dit on D1 and dah on D2 again
    Reverts b3a75fd. Dit is on the jack's tip (D1) and dah on the ring (D2),
    as on the ESP32-S3. Flashed to three boards.
2026-10-25 feat(enclosure): modular nRF52840 case, USB base unit with a screw-on battery tray
    Only the XIAO nRF52840 key is sold from now on, with or without a battery,
    and a key bought without one can get it later without soldering.
    The USB case becomes the base unit: 5 mm longer inside (49.5 mm) and as
    wide as the cell needs (25.3 mm outside); the board sits 5 mm above the
    floor so a JST-PH lead on the BAT pads (between D2 and D3) can wait under
    it, above a knock-out in the floor. Two bosses in the USB-end corners of
    the floor take the tray's screws; at the jack end a rebate with a groove
    takes its hooks. The snap lips at the USB end move to 6.7 mm, clear of
    the bosses.
    The battery tray is the base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
2026-10-27 README: get a ready-built key in the Ramus Labs Shop
    The shop replaces the parts-kit and assembled-key orders by email; building it
    yourself stays documented here. Longpath's BLE-key dialog now offers only the shop.
    Claude-Session: https://claude.ai/code/session_01BtmNy482enplh9tsjjzjdj
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
